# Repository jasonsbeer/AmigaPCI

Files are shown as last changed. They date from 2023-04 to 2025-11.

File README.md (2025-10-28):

<h1 align="center"></h1>

The AmigaPCI is an OCS/ECS Amiga computer in the ATX form factor. It provides a flexible CPU Local Bus port, five AUTOCONFIG PCI slots for expansion purposes such as video and sound, an on-board dual port ATA controller, and offers performance improvements over legacy Amiga designs.

## Features  
<list>
  <li>CPU Local Bus Card supports multiple CPU and fast RAM options</li>
  <li>Five AUTOCONFIG PCI 5V/Univeral slots</li>
  <li>PCI DMA allowing access to all Amiga and PCI address spaces</li>  
  <li>HID mouse and keyboard inputs</li>
  <li>Dual port IDE interface supporting up to 4 total devices</li>
  <li>Agnus 8372A or 8375 selectable by jumper</li>
  <li>Amiga Video Slot</li>
  <li>Floppy disk interface supports Amiga and PC drives in DD mode</li>
</list></br>

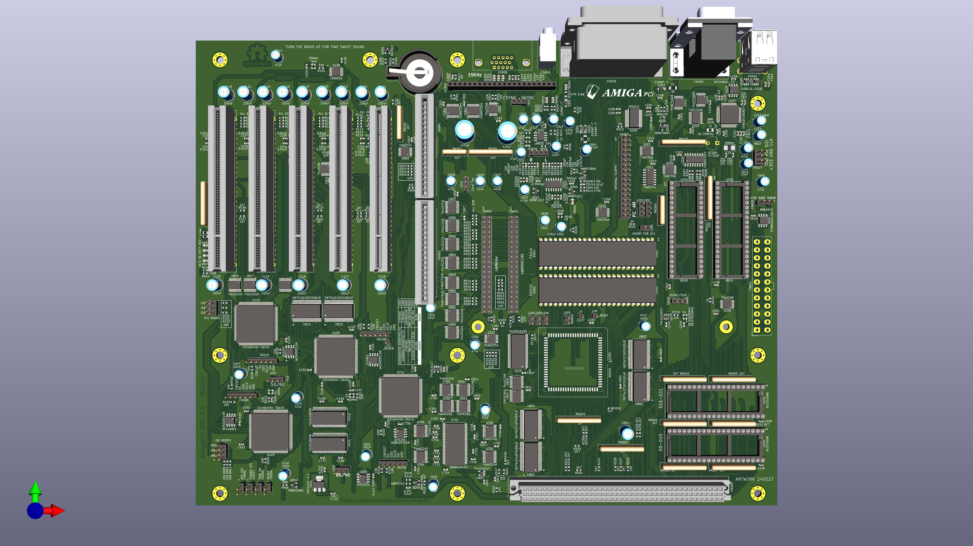
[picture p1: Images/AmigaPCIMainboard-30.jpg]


## Project Status  
**THIS IS A WORK IN PROGRESS AND IS SUBJECT TO CHANGE WITHOUT NOTICE.**

This is an active project and is currently in the prototype stage. Specifications are subject to change. Because this project is in the prototype stage, it is not recommended for general use at this time. There will be errors that adversely affect performance and the logic equations are not complete. If you choose to build this before final release, you accept all cost and risk associated with the decision.

I am not seeking hardware enhancement requests at this time, but feel free to post these in the issues section. Discussions can be found at Discord: https://discord.gg/NU7SPYfNFj.

## About the AmigaPCI Project

This is a hobby project. To me, the Amiga has a personality that PCs of any era cannot hope to replicate. I got my first Amiga, an A500, in 1992. In 1995, despite Commodore having gone out of business, I upgraded to a used A2000 with a GVP 030/SCSI card and flicker fixer. Even at this time we had a few Amiga shops hanging on. Around 1998 I relented and built a PC. The writing was on the wall for the Amiga and it was time to move on. The Amigas went into the closet, rarely to see the light. Sadly, like so many, I ended up selling my original machines only for my interest to rekindle years later. The purpose of my Amiga projects are to learn and hopefully share something of value with fellow Amigans by providing options for machines using modern components, whenever possible. This gave rise to the [A2000 EATX](https://github.com/jasonsbeer/Amiga-2000-EATX), the [N2630](https://github.com/jasonsbeer/Amiga-N2630), and now, the AmigaPCI.

# Building the AmigaPCI

[Ordering PCBs](pcb_order.md)  
[Assembly Notes](assembly.md)
[Hardware Information](hardware_info.md)  
[Programming the FPGAs](program_fpga.md)  

# Overview

## PCI Local Bus  
The PCI bus is based on the [PCI Local Bus Revision 2.3 specifications](/DataSheets/PCI/pci_23.pdf). The PCI Bridge implements a bidirectional asynchronous FIFO to facilitate data movements between the buses. Each slot is compatable with Universal and 5V PCI devices. All efforts are made to align implemented PCI features completely with the PCI Local Bus Revision 2.3. There are no undocumented PCI commands. Each slot is capable of supporting AUTOCONFIG for Amiga specific devices. Software configuration (Prometheus mode) is also available for non-Amiga specific hardware. The AmigaPCI supports true DMA, with each PCI device having total access to all PCI and Amiga address spaces.

## CPU Local Bus
The AmigaPCI main board has no CPU or fast ram. Instead, the CPU Local Bus port supports CPUs and AUTOCONFIG devices. The CPU Local Bus port is a DIN 41612 connector with 120 pins in 3 rows by 40 columns. The CPU local bus is discussed further in the [AmigaPCI Technical Reference Manual](/AmigaPCI_Technical_Manual.md). This approach allows fast RAM and other AUTOCONFIG devices be optimized for the clock speed and capabilities of the CPU device implemented.

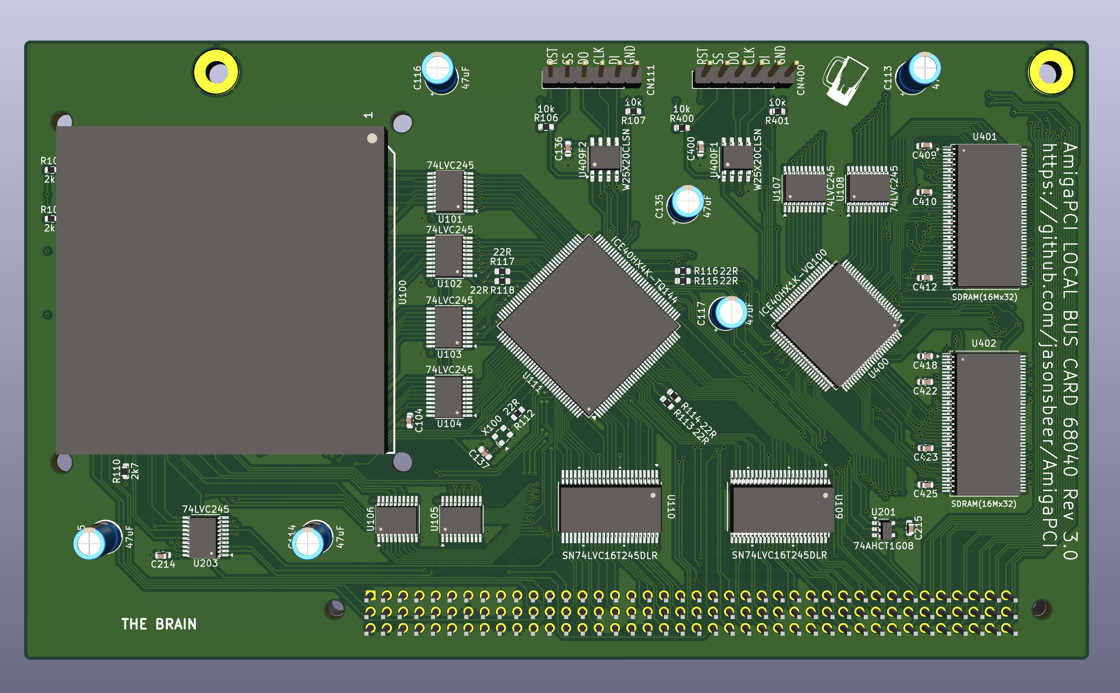
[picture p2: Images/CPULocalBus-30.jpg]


## Amiga Custom Chips  
The AmigaPCI must be populated with the Amiga OCS/ECS custom chips. The Amiga chipset is required to enable critical functions of the Amiga computer. See [Assembly Notes](assembly.md) for more information.

## Kickstart ROM  
Kickstart ROM version 3.2 or greater for the Amiga 1200 should be burned to 27C4096 EPROMs (DIP-40 footprint) for use by the AmigaPCI. Original Commodore Amiga Kickstart ROMs are not supported. 

## STM32F205 Microcontroller
The STM32F205 microcontroller supplies several functions to the AmigaPCI.

### HID
The AmigaPCI support human interface devices (HID) via the two USB ports. The mouse HID signals are shared with the JOY1 port (see Mouse and Joystick) via buffers. When there is active input from the HID mouse, the buffers are switched to only allow input from the HID port. When the HID mouse is not in active use, the buffers switch to allow input from JOY1. With this method, input from only one device is allowed at any time, with the mouse HID having priority.

### I2C
An internal I2C header is present on the AmigaPCI board as well as at the Local Bus Card.

### Real Time Clock
The STM32F205 emulates the capabilities of the xxxx real time clock chip. The clock is timed by an external 32.xxxkhz crystal and can be fine tuned by a variable capacitot.

### Voltage Monitors
All voltages can be monitored by reading registers from the real time clock address space.

### Internal temperature
The internal fan header RPM is controlled by a PWM signal.

## Audio  
The audio output is generated by Paula and run through the filter circuit as in the Amiga 4000. The audio output is supplied from a line level 3.5mm stereo jack. A CD audio header is included to support the input of analog line-level audio from optical drives or other devices. It is a 4-pin 2.54 pitch connector in the RGGL footprint, with pin 1 = R. This may be installed as a standard 4-pin male header or TE Connectivity part 5-103639-3, which is the MPC-2 locking header that has become ubiquitous.

## Video  
The 15KHz standard Amiga video is output via an HD15 connector. This allows easy connection to converter boxes or any monitors that support the 15KHz standard. This connector only includes the signals needed for video output. Other signals present on the orignal Amiga video port are not included.

## Mouse and Joystick
There are two legacy DB9 joystick port headers on the board. JOY1 is shared with the HID mouse input. In order to prevent signal contention with the HID mouse, the inputs from JOY1 are disconnected when the HID mouse is actively used. This prevents undesired behavior and allows only one device at a time to input signals, with the HID device having priority. See [HID](#hid). The input of JOY2 is not shared with other ports. 

## Serial  
The serial port is a male DB25 connector, which is stacked with the parallel female DB25 connector. The serial port is completely compatable with Amiga peripherals designed for the Amiga 500, 600, 1200, 2000, 3000, and 4000.

## Parallel  
The parallel port is a female DB25 connector, which is stacked with the serial male DB25 connector. The parallel port is completely compatable with legacy Amiga devices.

## Floppy Disk Drive  
The floppy disk interface is the primary way Amiga based computers store and retrieve external data. The AmigaPCI includes a header that supports two internal double density floppy disk drives.

In addition to supporting original Amiga floppy disk drives, the AmigaPCI supports PC floppy disk drives with double density floppies. An adaptation of Ian Steadman's [PC floppy interface](https://github.com/istedman/Floppy_adaptor) is implemented. The floppy drive hardware type (Amiga or PC) is set by jumper.

>[!NOTE]
>You must use either Amiga disk drives or PC disk drives. Do not mix the two types.  

## ATA  
The AmigaPCI includes a dual-port host terminated ATA device interface using [lide.device](https://github.com/LIV2/lide.device).

## Video Slot  
The AmigaPCI includes the Amiga OCS/ECS video bus. This allows for the use of OCS/ECS compatable video devices with the AmigaPCI.

# References

[AmigaPCI PCI Hardware Developer Reference](/AmigaPCI_PCI_Dev_Guide.md)  
[AmigaPCI Hardware Reference](/AmigaPCI_Technical_Manual.md)  
[PCI Local Bus Revision 2.3 specifications](/DataSheets/PCI/pci_23.pdf)  

# Revision History 
**Rev 6.0**  Current engineering prototype. 

# Acknowledgements  
Chris Hooper for his work on the STM32F205 microcontroller code.  
Frédéric Requin for helping me better understand the ATA protocol.  
Ian Steadman for his [Amiga PC floppy interface](https://github.com/istedman/Floppy_adaptor) design.

# License
Floppy interface modifications from Ian Steadman (noted in schematic) released under the GNU GENERAL PUBLIC LICENSE, Version 3.

<p xmlns:cc="http://creativecommons.org/ns#" xmlns:dct="http://purl.org/dc/terms/"><a property="dct:title" rel="cc:attributionURL" href="https://github.com/jasonsbeer/AmigaPCI">AmigaPCI</a> by <a rel="cc:attributionURL dct:creator" property="cc:attributionName" href="https://github.com/jasonsbeer">Jason Neus</a> is licensed under <a href="https://creativecommons.org/licenses/by-nc/4.0/?ref=chooser-v1" target="_blank" rel="license noopener noreferrer" style="display:inline-block;">Creative Commons Attribution-NonCommercial 4.0 International</a></p>

**Last Update: 28-OCT-2025**

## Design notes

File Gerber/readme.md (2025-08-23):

The gerbers are in the appropriate folder. Pick and place files and JLCPCB BOMs with parts numbers are also found in each folder. File names containing "SMT" are surface mount components only. File names containing "ALL PARTS" include SMT and through hole parts. Not all parts are necessarily populated in the BOM, as dictated by availability and (crazy) price at the time the files were created. Previous revision hardware can be found in the Archive folder.

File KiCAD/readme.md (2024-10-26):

KiCAD files. Current revisions are in this folder. Development (future) revisions are in the DEV folder. Deprecated versions are found in the Archive folder.

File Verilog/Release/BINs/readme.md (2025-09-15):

You will find the current FPGA BIN files here. These will always be the most recent revision.

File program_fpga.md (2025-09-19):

# Programming the FPGA Flash Memory
There are four Lattice iCE40 FPGAs on the AmigaPCI board. Each FPGA has an associated flash memory module to store the FPGA configuration, which is loaded by the FPGA at startup. Each flash memory module has a programming header. The header is identified similarly to the associated FPGA. For example, CN712 programs the flash module for U712. CN409 for U409, etc.

## Programming with a FT232H USB to SPI Board
We will discuss programming the flash memory modules using iceprog with cheap FTDI FT232H interface boards. Such an example is the [Adafruit FT232H](https://www.adafruit.com/product/2264). Similar boards can be obtained from other manufacturers. The following steps describe how to program the flash modules. Do not leave the AmigaPCI powered on for longer than necessary during the programming process.

It is recommended to program the FPGA's in specific order. Program any FPGAs on the local bus card first. If you have the AmigaPCI local bus card ("THE BRAIN") program these in this order: U400, U111. Then, on the AmigaPCI, program these in this order: U409, U712, U110, U109.

1. Install [icestorm](https://github.com/YosysHQ/icestorm).  

   Debian:
   ```
   sudo apt install fpga-icestorm
   ```
   Fedora:
   ```
   sudo dnf install icestorm
   ```

2. If it is on, turn off the AmigaPCI.
3. Connect the FT232H board to the desired FPGA programming port.
   
   AmigaPCI|Adafruit FT232H|C232HM MPSSE
   -|-|-
   GND|GND|Black/GND
   SDI|D1/MOSI|Yellow/DO
   SCLK|D0/SCK/SCL|Orange/SK
   SDO|D2/MISO|Green/DI
   SS|D4|Gray/GPIOL0
   CRST|D7|Blue/GPIOL3

3. Turn the AmigaPCI on.  
4. Execute iceprog with the correct BIN file.  

   ```
   iceprog U712.bin
   ```
5. Repeat steps 2 through 5 for each FPGA. Power cycle the AmigaPCI once complete.

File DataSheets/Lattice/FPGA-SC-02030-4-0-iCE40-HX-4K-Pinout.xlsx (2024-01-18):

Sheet: Pinout
iCE40 Pinout HX4K
Pin Function | Pin Type | Bank | (BG121) 121-Ball caBGA Ball Number | (CB132) 132-Ball csBGA Ball Number | (TQ144) 144-Pin TQFP Pin Number
IOL_2A | DPIO | 3 | B1 | B1 | 1
IOL_2B | DPIO | 3 | B2 | C1 | 2
IOL_3A | DPIO | 3 | - | - | 3
IOL_3B | DPIO | 3 | - | - | 4
GND | GND | GND | - | A9 | 5
VCCIO_3 | VCCIO | VCCIO | - | E3 | 6
IOL_4A | DPIO | 3 | C4 | C3 | 7
IOL_4B | DPIO | 3 | C3 | D3 | 8
IOL_5A | DPIO | 3 | C2 | D1 | 9
IOL_5B | DPIO | 3 | C1 | E1 | 10
IOL_8A | DPIO | 3 | E1 | D4 | 11
IOL_8B | DPIO | 3 | D1 | E4 | 12
IOL_9A | DPIO | 3 | D2 | F4 | -
IOL_9B | DPIO | 3 | D3 | F3 | -
GND | GND | GND | - | F1 | 13
GND | GND | GND | - | F7 | 14
IOL_10A | DPIO | 3 | E2 | H4 | 15
IOL_10B | DPIO | 3 | E3 | G4 | 16
IOL_12A | DPIO | 3 | F1 | J3 | 17
IOL_12B | DPIO | 3 | F2 | J1 | 18
IOL_13A | DPIO | 3 | F4 | G3 | 19
IOL_13B_GBIN7 | GBIN | 3 | F3 | G1 | 20
IOL_14A_GBIN6 | GBIN | 3 | G1 | H1 | 21
IOL_14B | DPIO | 3 | G2 | H3 | 22
IOL_17A | DPIO | 3 | G3 | - | 23
IOL_17B | DPIO | 3 | H3 | - | 24
IOL_18A | DPIO | 3 | H1 | K3 | 25
IOL_18B | DPIO | 3 | H2 | K4 | 26
VCC | VCC | VCC | - | F8 | 27
IOL_23A | DPIO | 3 | J1 | L1 | 28
IOL_23B | DPIO | 3 | K1 | M1 | 29
VCCIO_3 | VCCIO | VCCIO | E4 | J6 | 30
IOL_24A | DPIO | 3 | - | - | 31
IOL_24B | DPIO | 3 | - | - | 32
IOL_25A | DPIO | 3 | K2 | N1 | 33
IOL_25B | DPIO | 3 | J2 | P1 | 34
IOB_56 | PIO | 2 | L1 | P2 | 37
IOB_57 | PIO | 2 | J3 | - | 38
IOB_59 | PIO | 2 | - | P3 | -
IOB_61 | PIO | 2 | L2 | - | 39
VCC | VCC | VCC | D8 | G6 | 40
IOB_63 | PIO | 2 | K3 | M4 | 41
IOB_64 | PIO | 2 | J4 | M3 | 42
IOB_71 | PIO | 2 | L3 | L5 | 43
IOB_72 | PIO | 2 | L4 | L4 | 44
IOB_73 | PIO | 2 | K4 | P4 | 45
IOB_74 | PIO | 2 | - | P5 | -
IOB_77 | PIO | 2 | - | M6 | -
IOB_78 | PIO | 2 | J5 | L6 | -
VCCIO_2 | VCCIO | VCCIO | H6 | J9 | 46
IOB_79 | PIO | 2 | K5 | M7 | 47
IOB_80 | PIO | 2 | - | - | 48
IOB_81_GBIN5 | GBIN | 2 | L5 | P7 | 49
IOB_82_GBIN4 | GBIN | 2 | K6 | P8 | 52
GNDPLL0 | GNDPLL | GNDPLL | L6 | L7 | 53
VCCPLL0 | VCCPLL | VCCPLL | J6 | M8 | 54
IOB_87 | PIO | 2 | H7 | L8 | -
IOB_89 | PIO | 2 | K7 | P9 | -
IOB_91 | PIO | 2 | J8 | M9 | 55
IOB_94 | PIO | 2 | L7 | - | 56
VCCIO_2 | VCCIO | VCCIO | - | M5 | 57
GND | GND | GND | E5 | G7 | 59
IOB_95 | PIO | 2 | - | - | 60
IOB_96 | PIO | 2 | - | - | 61
IOB_102 | PIO | 2 | - | - | 62
IOB_103_CBSEL0 | PIO | 2 | L8 | L9 | 63
IOB_104_CBSEL1 | PIO | 2 | H9 | P10 | 64
CDONE | CONFIG | 2 | K8 | M10 | 65
CRESET_B | CONFIG | 2 | L9 | L10 | 66
IOB_105_SDO | SPI | SPI | K9 | M11 | 67
IOB_106_SDI | SPI | SPI | J9 | P11 | 68
GND | GND | GND | E6 | G8 | 69
IOB_107_SCK | SPI | SPI | L10 | P12 | 70
IOB_108_SS | SPI | SPI | K10 | P13 | 71
VCC_SPI | SPI | SPI | L11 | L11 | 72
IOR_109 | PIO | 1 | - | M12 | 73
IOR_110 | PIO | 1 | - | P14 | 74
IOR_111 | PIO | 1 | - | L12 | 75
IOR_112 | PIO | 1 | - | N14 | 76
NC | NC | NC | - | M14 | 77
IOR_114 | PIO | 1 | J11 | L14 | 78
IOR_115 | PIO | 1 | K11 | K12 | 79
IOR_116 | PIO | 1 | H10 | K11 | 80
IOR_117 | PIO | 1 | J10 | K14 | 81
IOR_118 | PIO | 1 | G8 | J12 | 82
IOR_119 | PIO | 1 | H11 | J11 | 83
IOR_120 | PIO | 1 | G10 | H12 | 84
IOR_128 | PIO | 1 | G9 | H11 | 85
IOR_129 | PIO | 1 | G11 | G12 | -
GND | GND | GND | E7 | G9 | 86
IOR_136 | PIO | 1 | F10 | G11 | 87
IOR_137 | PIO | 1 | F9 | F12 | 88
VCCIO_1 | VCCIO | VCCIO | - | F9 | 89
IOR_138 | PIO | 1 | - | - | 90
IOR_139 | PIO | 1 | - | - | 91
VCC | VCC | VCC | D4 | H9 | 92
IOR_140_GBIN3 | GBIN | 1 | F11 | F14 | 93
IOR_141_GBIN2 | GBIN | 1 | E10 | G14 | 94
IOR_144 | PIO | 1 | E9 | F11 | 95
IOR_146 | PIO | 1 | E8 | E11 | 96
IOR_147 | PIO | 1 | D9 | E12 | 97
IOR_148 | PIO | 1 | E11 | E14 | 98
IOR_152 | PIO | 1 | D11 | D14 | 99
IOR_154 | PIO | 1 | D10 | C14 | -
VCCIO_1 | VCCIO | VCCIO | F8 | H14 | 100
IOR_160 | PIO | 1 | C11 | D12 | 101
IOR_161 | PIO | 1 | B11 | B14 | 102
GND | GND | GND | F5 | H6 | 103
IOR_164 | PIO | 1 | - | - | 104
IOR_165 | PIO | 1 | - | - | 105
IOR_166 | PIO | 1 | - | - | 106
IOR_167 | PIO | 1 | - | - | 107
VPP_2V5 | VPP | VPP | C10 | A14 | 108
VPP_FAST | VPP | VPP | B10 | A13 | 109
IOT_168 | PIO | 0 | A11 | - | 110
VCC | VCC | VCC | H4 | J4 | 111
IOT_169 | PIO | 0 | - | - | 112
IOT_170 | PIO | 0 | A10 | A12 | 113
IOT_171 | PIO | 0 | - | - | 114
IOT_172 | PIO | 0 | C9 | C12 | 115
IOT_173 | PIO | 0 | - | - | 116
IOT_174 | PIO | 0 | B9 | C11 | 117
IOT_177 | PIO | 0 | B8 | D10 | 118
IOT_178 | PIO | 0 | A9 | D11 | 119
IOT_179 | PIO | 0 | C8 | A11 | 120
IOT_181 | PIO | 0 | D7 | A10 | 121
IOT_186 | PIO | 0 | - | C10 | -
IOT_188 | PIO | 0 | - | D9 | -
IOT_190 | PIO | 0 | A8 | C9 | 122
VCCIO_0 | VCCIO | VCCIO | D6 | A8 | 123
IOT_191 | PIO | 0 | C7 | - | 124
IOT_192 | PIO | 0 | A7 | - | 125
VCCPLL1 | VCCPLL | VCCPLL | C6 | C8 | 126
GNDPLL1 | GNDPLL | GNDPLL | C5 | D8 | 127
IOT_197_GBIN1 | GBIN | 0 | B7 | A7 | 128
IOT_198_GBIN0 | GBIN | 0 | B6 | A6 | 129
IOT_200 | PIO | 0 | - | C7 | -
IOT_202 | PIO | 0 | - | D7 | -
IOT_206 | PIO | 0 | A6 | C6 | 130
IOT_207 | PIO | 0 | A5 | D6 | -
IOT_208 | PIO | 0 | B5 | A5 | -
IOT_211 | PIO | 0 | A4 | D5 | -
VCCIO_0 | VCCIO | VCCIO | - | F6 | 131
GND | GND | GND | F6 | H7 | 132
IOT_212 | PIO | 0 | D5 | C5 | 134
IOT_213 | PIO | 0 | - | - | 135
IOT_214 | PIO | 0 | - | - | 136
IOT_215 | PIO | 0 | - | - | 137
IOT_216 | PIO | 0 | - | - | 138
IOT_217 | PIO | 0 | - | - | 139
GND | GND | GND | F7 | H8 | 140
IOT_219 | PIO | 0 | B4 | A4 | 141
IOT_220 | PIO | 0 | - | - | 142
IOT_221 | PIO | 0 | B3 | C4 | 143
IOT_222 | PIO | 0 | A2 | A3 | 144
IOT_223 | PIO | 0 | A3 | A2 | -
IOT_225 | PIO | 0 | A1 | A1 | -
VCC | VCC | VCC | H8 | J7 | -
NC | NC | NC |  | - | 35
NC | NC | NC |  | - | 36
NC | NC | NC |  | - | 50
NC | NC | NC |  | - | 51
NC | NC | NC |  | - | 58
NC | NC | NC |  | - | 133
GND | GND | GND | G5 | J14 | -
GND | GND | GND | G6 | J8 | -
GND | GND | GND | G7 | L3 | -
GND | GND | GND | H5 | P6 | -
VCCIO_3 | VCCIO | VCCIO | G4 | K1 | -
IOB_86 | PIO | 2 | J7 | - | -

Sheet: Revision History
Version | Date | Description
4.0 | 2021/10/29 | Added the missing pins (D6, H4, H5, and J7)
3.0 | 2017/05/5 | add "BG121" for "121-Ball caBGA"(new 9x9 mm package ucBGA121), Revision "iCE40HX08.pkt 1.1"
2.1 | 2013-06-13 | Included package ordering code.
2.0 | 2013-03-13 | Updated table format to include all packages
1.0 | 10/1/2012 | Changed name from "TQ144" to "144-pin TQFP" Production Release
0.92 | 2011-12-14 | Package drawing, removed option notes 6 and 7
0.91 | 2011-11-13 | 1K pins 40, 49, 50, 52, 133, 134 updated
0.9 | 2011-10-31 | Preliminary

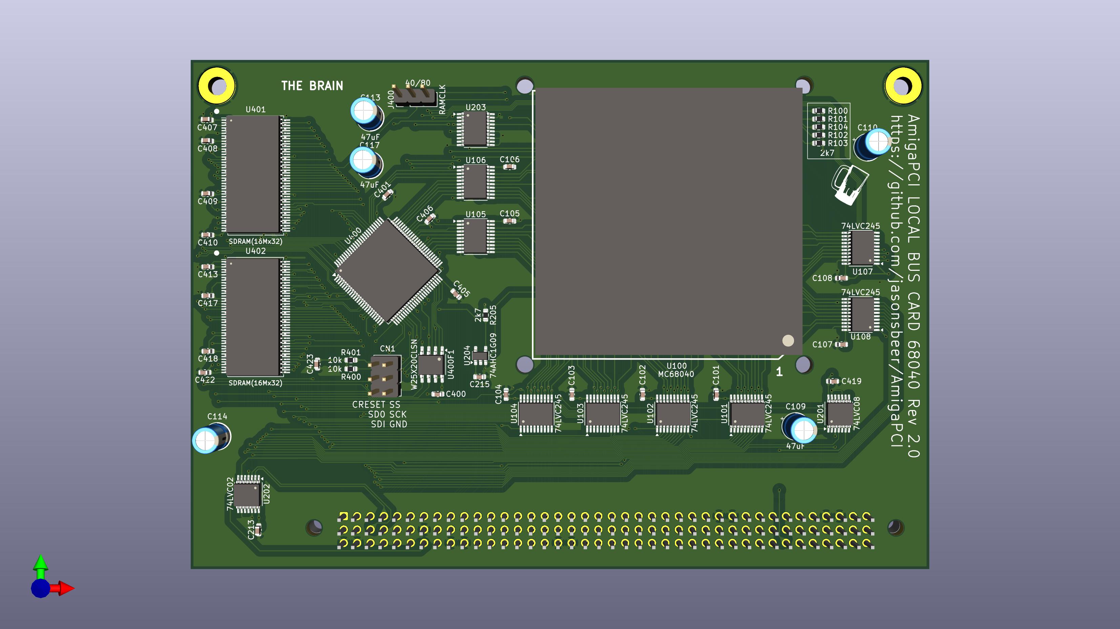
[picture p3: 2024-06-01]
Images/CPULocalBus-20.jpg

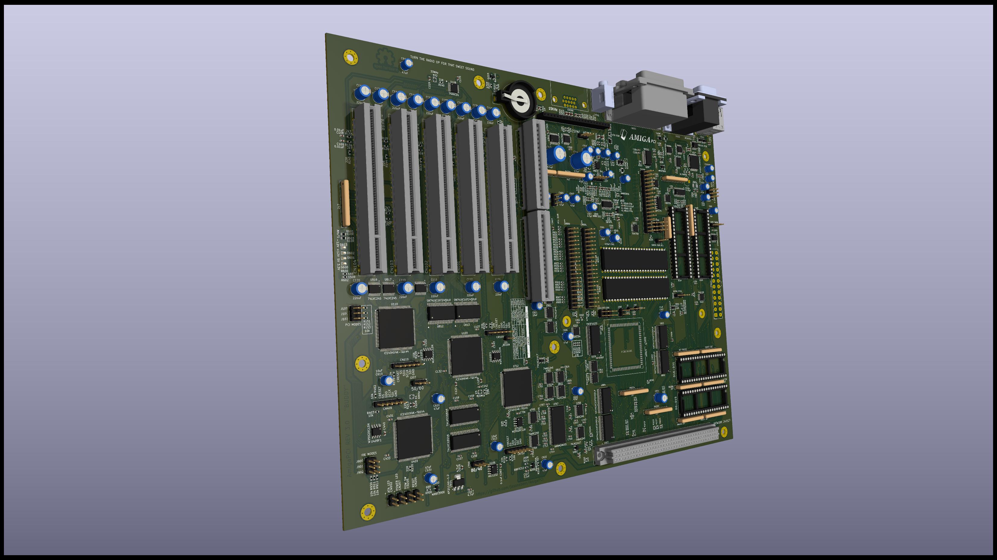
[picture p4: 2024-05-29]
Images/AmigaPCIMainboard-30a.jpg

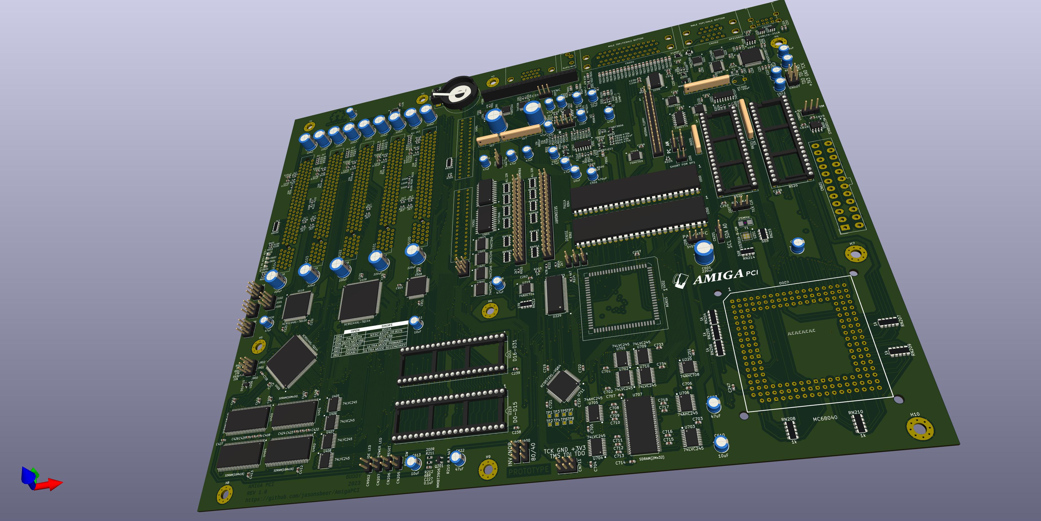
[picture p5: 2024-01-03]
Images/AmigaPCIMainboard.jpg

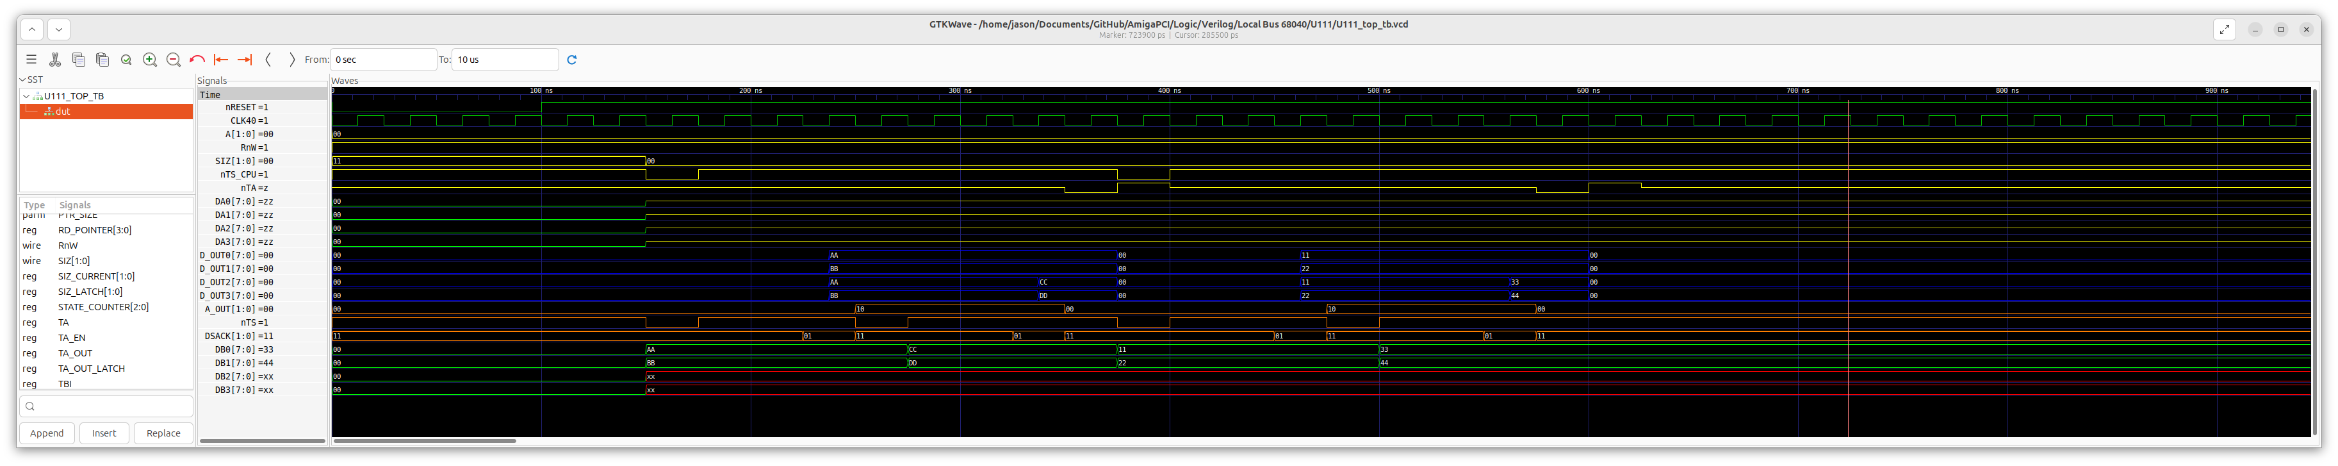
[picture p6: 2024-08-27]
DataSheets/TimingDiagrams/Bus Sizing/LONG WORD READ FROM WORD PORT.png

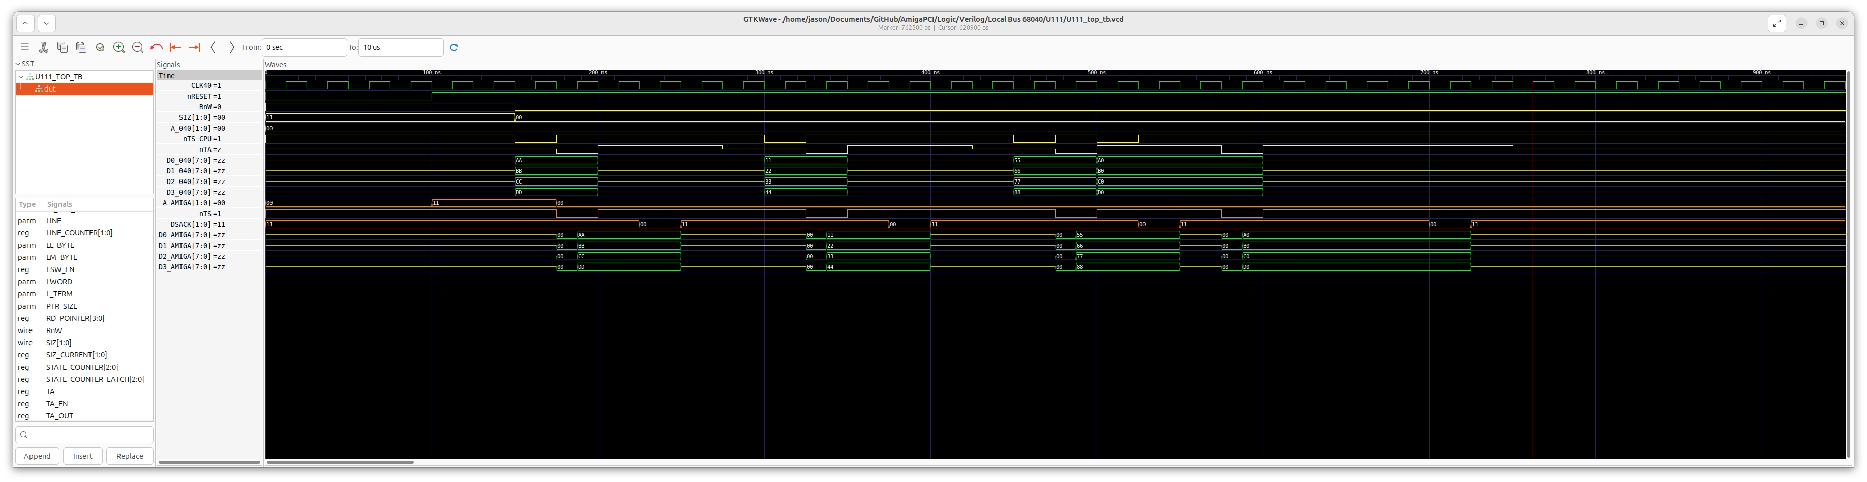
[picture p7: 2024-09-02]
DataSheets/TimingDiagrams/Bus Sizing/LONG WORD WRITE TO LONG WORD PORT.png

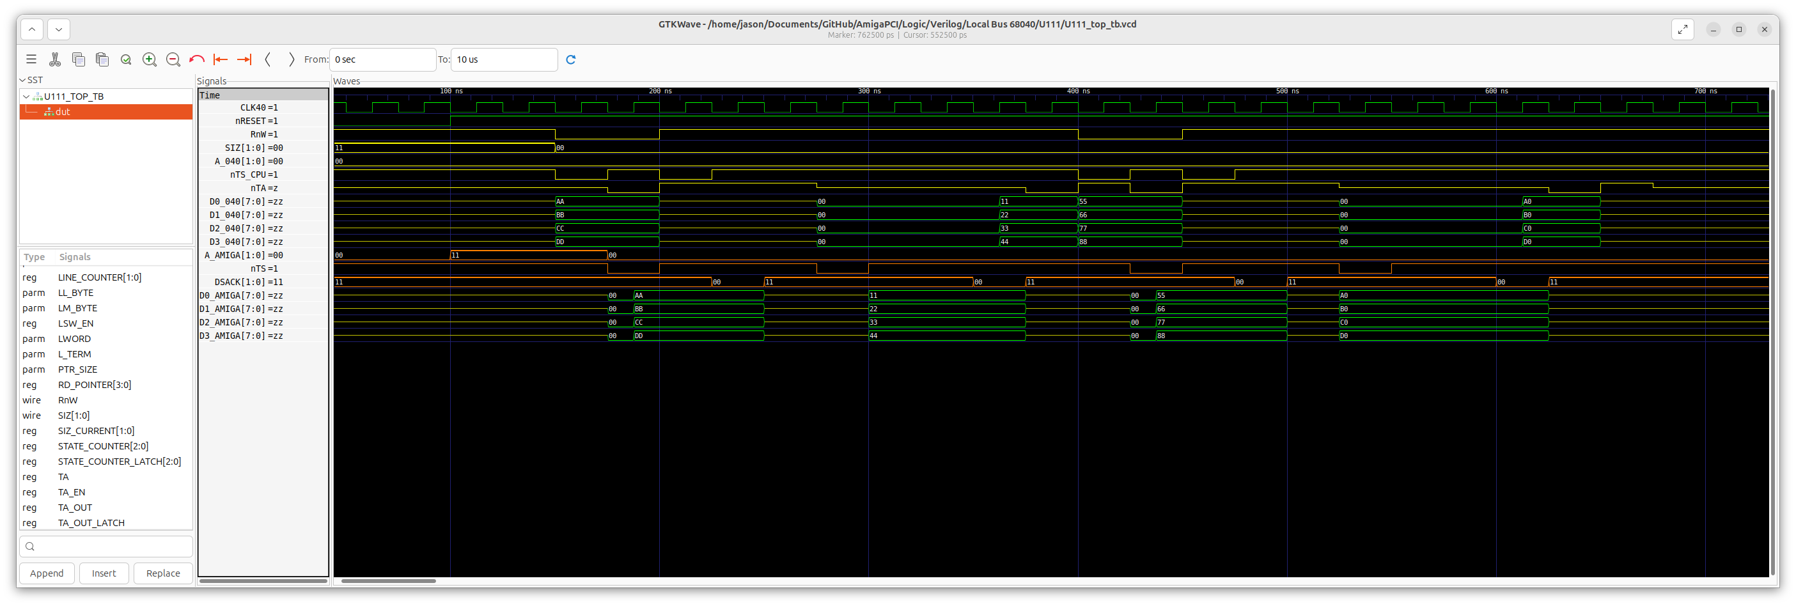
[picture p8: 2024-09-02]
DataSheets/TimingDiagrams/Bus Sizing/ALTERNATING RW LONG WORD TO LONG WORD PORT.png

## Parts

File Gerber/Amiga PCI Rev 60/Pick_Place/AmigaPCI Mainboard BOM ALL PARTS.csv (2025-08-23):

Value | Reference | Footprint | LCSC Part Number
7pF | C222 | 603 | C53775
13pF | C220,C221 | 603 | C34243
47pF | C307 | 603 | C1671
100pF | C301,C304,C312,C315,C316 | 603 | C14858
330pF | C518,C519 | 603 | C1664
1000pF | C234,C235,C236 | 603 | C1588
3900pF | C516,C517 | 603 | C170145
6800pF | C515,C524 | 603 | C1631
0.01uF | C100,C101,C102,C103,C104,C105,C106,C107,C108,C109,C210,C514 | 603 | C57112
0.047uF | C202,C203,C204,C205,C512,C513 | 603 | C1622
0.1uF | C123,C124,C125,C126,C127,C128,C129,C130,C131,C132,C135,C137,C139,C140,C141,C142,C143,C144,C145,C146,C147,C148,C150,C152,C153,C156,C157,C158,C159,C200,C201,C206,C207,C208,C209,C211,C213,C214,C215,C218,C219,C223,C224,C227,C228,C229,C230,C231,C232,C233,C238,C239,C241,C243,C246,C249,C250,C251,C252,C253,C256,C257,C258,C259,C261,C262,C263,C267,C302,C303,C305,C306,C420,C421,C429,C430,C431,C432,C433,C434,C435,C436,C438,C440,C500,C510,C511,C615,C616,C701,C702,C703,C704,C705,C706,C707,C708,C709,C710,C711,C712,C713,C714,C715,C716,C717,C718,C719,C720,C721,C722,C723,C724,C725,C726,C727,C728,C730,C736,C802,C803,C804,C805,C806,C807,C808,C809,C810,C811,C812,C813,C814,C815,C816,C817,C818,C819,C820,C821,C822,C823,C824,C825,C900,C901,C902,C904,C905,C906,C907,C908 | 603 | C14663
0.22uF | C300,C506,C508,C509 | 603 | C21120
1uF | C212 | 603 | C15849
4.7uF | C507 | Radial_D5.0mm_P2.00mm | C88759
4.7uF | C617,C618,C623,C626 | 603 | C19666
10uF | C136,C138,C149,C151,C437,C439,C729,C735 | 603 | C96446
10uF | C608,C611,C613,C619,C625 | Radial_D5.0mm_P2.00mm | C88726
22uF | C237,C240,C520,C521 | Radial_D5.0mm_P2.00mm | C88755
47uF | C522,C523,C600,C602,C603,C604,C605,C606,C607,C609,C610,C614,C620,C621,C622,C624 | Radial_D5.0mm_P2.00mm | C88724
68uF | C216,C217 | Radial_D5.0mm_P2.00mm | C439891
220uF | C110,C111,C112,C113,C114,C115,C116,C117,C118,C119,C120,C121,C133,C134,C601 | Radial_D6.3mm_P2.50mm | C141282
470uF | C313,C314,C501 | Radial_D10.0mm_P5.00mm | C59353
1R | R302,R500,R503,R504 | 603 | C22936
4A | F1,F2 | 1206 | C1972812
22R | R140,R141,R142,R143,R144,R145,R213,R215,R216,R217,R219,R220,R272,R273,R274,R275,R307,R907,R908,R909,R910,R913,R914,R915,R916,R917,R918,R919,R920,R921,R922,R923,R924,R925,R926,R927,R928,R929,R931,R932,R933,R934,R935,R936 | 603 | C23345
47R | R222,R226,R230,R231,R232,R233,R237,R301,R304,R313,R314,R315,R316,R317,R318,R319,R320,R321,R322,R323,R324 | 603 | C23182
68R | R204,R205,R206,R207,R211,R218,R251,R252 | 603 | C25254
100R | R156,R157,R160,R161,R400,R401,R700,R701 | 603 | C22775
200R | R212,R247 | 603 | C8218
470R | R201 | 603 | C23179
750R | R505,R507 | 603 | C23241
1k | R214,R224,R225,R227,R248,R249,R254,R255,R256,R257,R258,R259,R262,R263,R264,R268,R303,R309,R311,R312,R501,R502,R522,R523,R524,R526,R900 | 603 | C21190
1k | RN305 | SIP6 | C1357978
2k | R602,R906 | 603 | C22975
8362 | U300 | DIP-48 | C5510465
8364 | U500 | DIP-48 | C5510465
DIP-40 Socket | U203,U204,U210,U211 | DIP-40 | C2332
10k | R154,R155,R158,R159,R200,R202,R203,R208,R209,R223,R228,R229,R241,R265,R266,R279,R300,R305,R308,R402,R403,R509,R510,R511,R513,R515,R516,R517,R525,R702,R703,R901,R902,R903,R904,R911,R912 | 603 | C25804
10k | RN211 | SIP9 | C8692
32.768KHz | Y4 | 2Pin_3.2x1.5mm | C20340322
470k | R508,R514 | 603 | C23178
6MHz | X1 | 4Pin_2.5x2.0mm | C2451074
8MHz | Y1 | 2Pin_5.0x3.2mm | C5564812
28.63636MHz | X3 | 4Pin_2.5x2.0mm | C1670933
33MHz | X2 | 4Pin_2.5x2.0mm | C17506154
1x03 Pin Header | J201,J202,J303,J209,J208,J207,J206,CN209 | 1x03_P2.54mm_Vertical | C49257
1k2 | R506 | 603 | C22765
1N4148 | D200,D204 | SOD-323 | C118873
2k2 | R267,R280,R281,R600 | 603 | C4190
2k4 | R518,R519 | 603 | C22940
2k7 | R101,R102,R103,R104,R105,R106,R107,R108,R109,R110,R111,R112,R113,R114,R115,R116,R117,R118,R119,R120,R121,R122,R123,R124,R125,R126,R127,R128,R129,R130,R131,R132,R133,R134,R135,R136,R137,R138,R139,R146,R147,R148,R149,R150,R162,R221,R234,R235,R236,R238,R239,R240,R242,R243,R244,R245,R246,R269,R270,R271,R276,R277,R278,R512 | 603 | C13167
2k7 | RN100,RN200,RN201,RN202,RN203,RN204,RN205,RN206,RN207 | SIP9 | C5902812
2k7 | RN101 | SIP7 | C51837
47R 0.5W | R310 | 805 | C560533
4k7 | R210,R520,R521 | 603 | C23162
4k7 | RN208,RN213,RN302 | SIP5 | C11392
4k7 | RN301 | SIP9 | C9112
5-20pF | VC200 | 6mm Lead Spacing | C3273401
5k1 | R260,R261 | 603 | C23186
5k1 | R601,R603 | 805 | C27834
74AHC04 | U108,U219 | TSSOP-14 | C415550
74AHC1G09 | U232 | SOT23-5 | C840099
74AHCT157 | U224 | SOIC-16 | C5969
74AHCT244 | U301,U302 | TSSOP-20 | C135583
74AHCT245 | U201 | TSSOP-20 | C173388
74CBT16233 | U229 | SSOP-56 | C2674759
74HCT00 | U213 | TSSOP-14 | C8206
74HCT03 | U215 | TSSOP-14 | C546492
74HCT08 | U209,U305 | TSSOP-14 | C131488
74HCT74 | U212,U303 | TSSOP-14 | C141335
74HCT4066 | U221,U222 | TSSOP-14 | C26433
74LVC08 | U220,U231,U815 | TSSOP-14 | C6053
74LVC245 | U701,U702,U703,U704,U705,U706,U806,U807,U808,U809,U812,U813,U814,U816,U817,U818,U819,U900,U901,U902,U903,U904,U905 | TSSOP-20 | C7848
74LVC373 | U906,U907 | TSSOP-20 | C485083
74LVC16646 | U111,U112,U810 | SSOP-56 | C2869631
74LVC2G34 | U200 | SOT -363 | C14461
_KBRST | CN210 | PinHeader_1x01_P2.54mm_Vertical | C81276
2X03 Pin Header | AGNUS1,JIDE1,JPCI1 | 2x03_P2.54mm_Vertical | C124384
Agnus_MULTI | U202 | PLCC-84 | C5445002
AO3400A | Q202 | SOT-23 | C347475
AP2114H-1.2 | U601 | SOT-223 | C94854
AP2114H-3.3 | U600 | SOT-223 | C150716
AP2156SG-13 | U228 | SOIC-8 | C88233
ATX-24 | CN601 | 2x12_P4.20mm_Vertical | C114088
AudioJack | CN501 | SJ1-3533NG_Horizontal | C4992459
AZ75232G | U205,U207 | TSSOP-20 | C444988
Battery_Cell | BT2 | Keystone_103_1x20mm | C238065
BZT52C5V1 | D205 | SOD-123 | C2117
Case Fan | CN205 | 1x04_P2.54mm_Vertical | C240840
CASE HDR | JCASE1 | 2x04_P2.54mm_Vertical | C7430400
DB15_Female_HighDensity | CN300 |  | C379814
DB25_Stack_FemaleAndMale | CN203 | DSUB-25_Stack_Female_Bottom_Male_Top | C17554757
DSP/DVD (RGGL) | CN500 | 1x04_P2.54mm_Vertical | C306099
ESDS452 | D206,D207,D208,D209,D210,D211,D212 | SOT-23 | C37574382
I2C | CN206 | 1x04_P2.54mm_Vertical | C124378
ICE40HX4K-TQ144 | U109,U110,U409,U712 | LQFP-144 | C1521989
INTERNAL FLOPPY | CN204 | PinHeader_2x17_P2.54mm | C2685134
LED | D203,D600,D601,D602,D603 | 603 | C2286
LF347 | U501 | SOIC-14 | C7917
LM833 | U502 | SOIC-8 | C127074
LM79L05 | U602 | SOIC-8 | C7555
MIC1232 | U206 | SOIC-8 | C627729
MMBFJ211 | Q500,Q501 | SOT-23 | C3290016
MMBT3904 | Q200 | SOT-23 | C84104
MMBT3906 | Q201,Q502,Q900 | SOT-23 | C75549
PCI32-5V | CN100,CN101,CN102,CN103,CN104 | 1.27mm Direct Insert 120P | C4900616
ATA HEADER | CN900,CN901 | PinHeader_2x20_P2.54mm_Vertical | C429965
1x02 Pin Header | J200,J203,J210,TP_109 | 1x02_P2.54mm_Vertical | C124375
ROM WAIT | J212 | 2x02_P2.54mm_Vertical | C66690
S1MWF-7 | D201,D202,D301,D400 | SOD-123 | C460736
SDRAM(8Mx32) | U707 | TSOP-II-86 | C1351836
SN74LVC16T245DLR | U802,U803,U804,U805 | BSSOP-48 | C2682002
SST39VF1601C | U223 | TSOP-I-48 | C184156
STM32F205RETx | U227 | LQFP-64 | C66278
Programming Header | CN227,CN109,CN110,CN409,CN712 | 1x06_P2.54mm_Vertical | C37208
USB_A_Stacked | CN201 | USB-A | C5366339
USBLC6-2SC6 | U225,U226 | SOT-23 | C7519
Video-Slot | CN301,CN302 | 2x18_P2.54mm_Horizontal | C5173302
VIDIOT | HY300 | PinSocket_1x22_P2.54mm_Vertical | C6358405
W25X20CLSN | U109F1,U110F1,U409F1,U712F1 | SOIC-8 | C34591

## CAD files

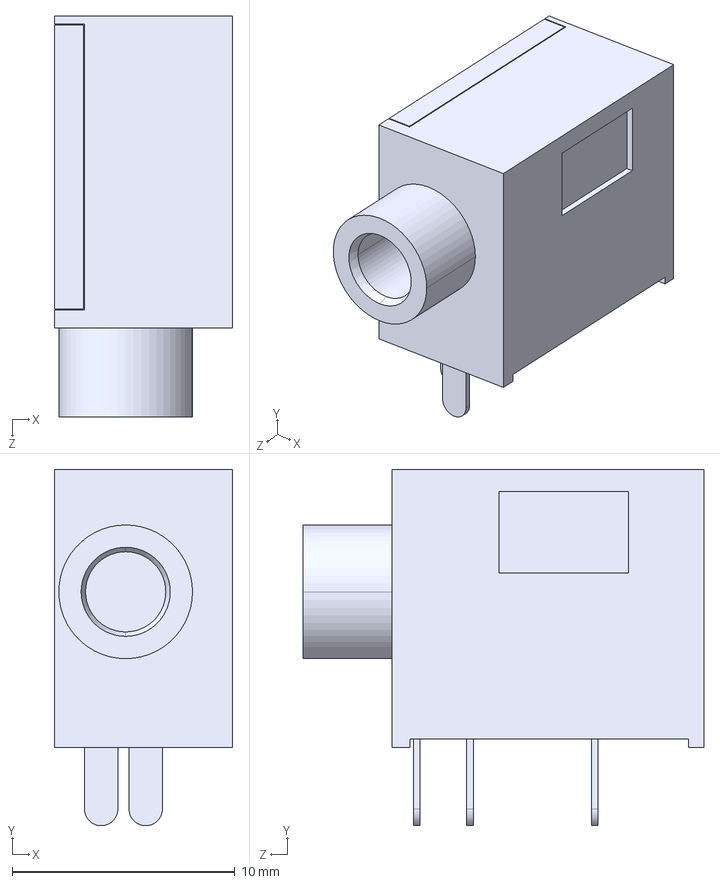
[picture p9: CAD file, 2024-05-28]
KiCAD/AmigaPCI Mainboard-KiCAD REV 60/AmigaPCI-Footprints/CUI_DEVICES_SJ1-3533N.step
8.00 x 16.0 x 18.0 mm

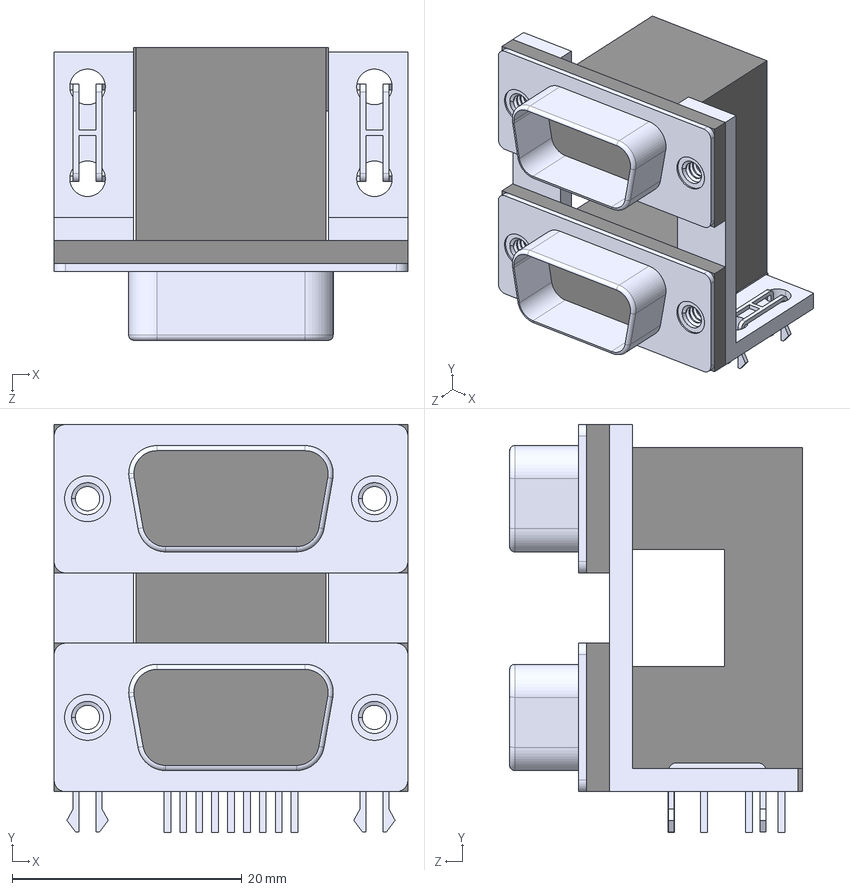
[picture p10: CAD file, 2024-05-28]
KiCAD/AmigaPCI Mainboard-KiCAD REV 60/AmigaPCI-Footprints/L17H2110130.step
30.8 x 35.5 x 25.5 mm

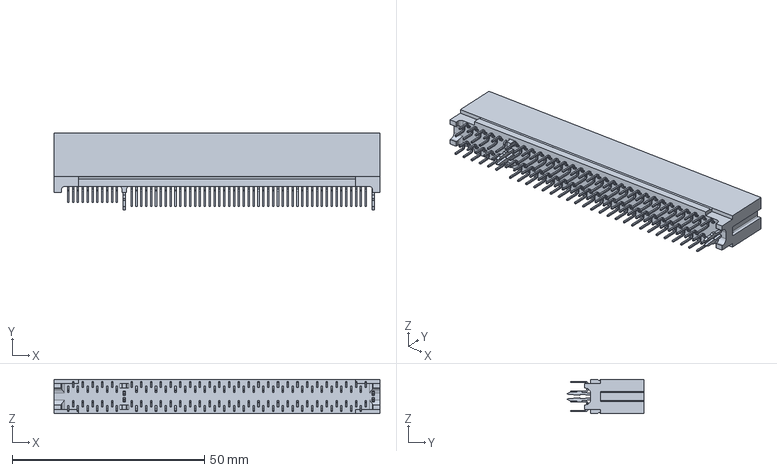
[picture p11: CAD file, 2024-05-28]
KiCAD/AmigaPCI Mainboard-KiCAD REV 60/AmigaPCI-Footprints/1-5145167-2.STEP
84.8 x 20.1 x 8.89 mm

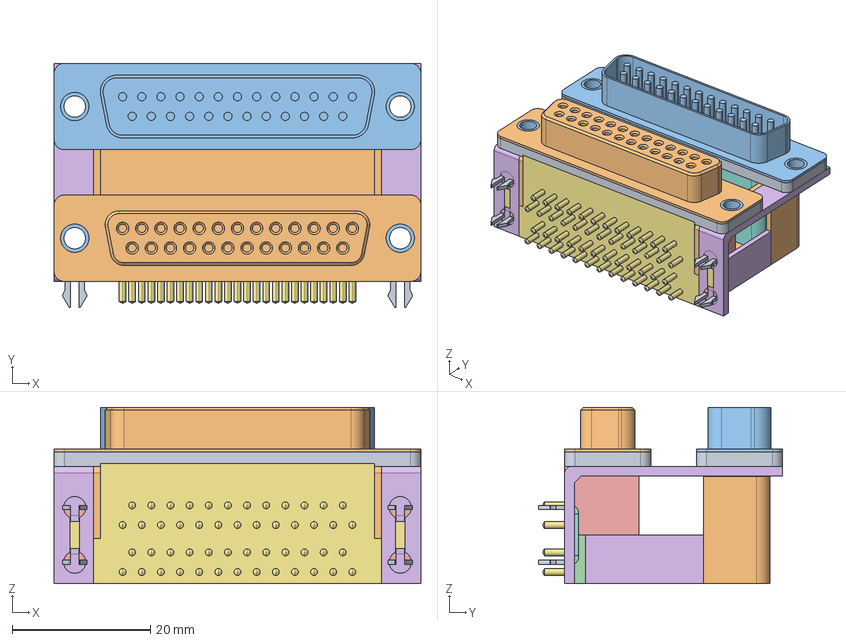
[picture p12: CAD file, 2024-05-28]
KiCAD/AmigaPCI Mainboard-KiCAD REV 60/AmigaPCI-Footprints/asub-277-25tp24.stp
53.1 x 35.3 x 25.5 mm

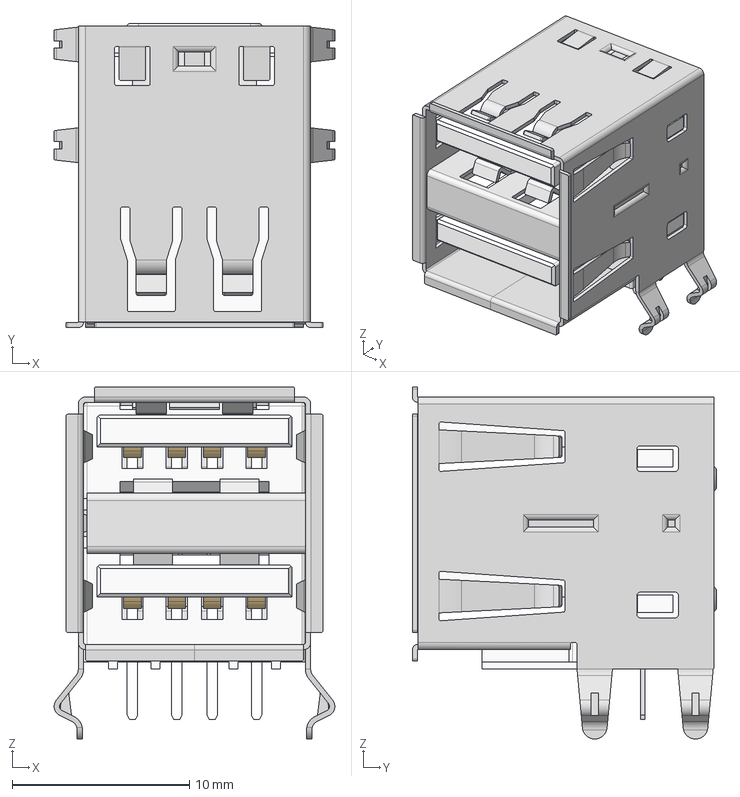
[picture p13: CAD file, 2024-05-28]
KiCAD/AmigaPCI Mainboard-KiCAD REV 60/AmigaPCI-Footprints/61400826021--3DModel-STEP-898076.STEP
15.8 x 17.1 x 19.8 mm
61400826021_Shielding1
61400826021_Housing
61400826021_Shielding2
61400826021_Pin2 x 4
61400826021_Pin1 x 4
61400826021_Shielding3

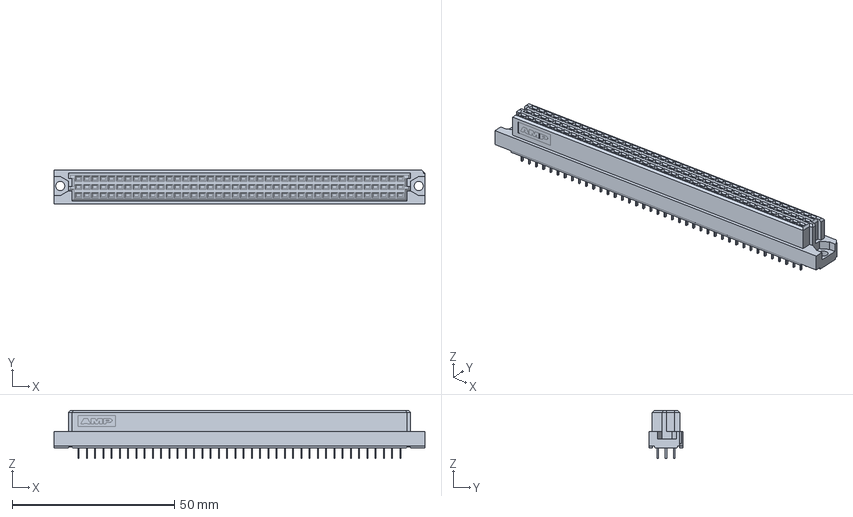
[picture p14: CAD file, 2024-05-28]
KiCAD/AmigaPCI Mainboard-KiCAD REV 60/AmigaPCI-Footprints/5535098-5.stp
114.2 x 10.6 x 14.8 mm

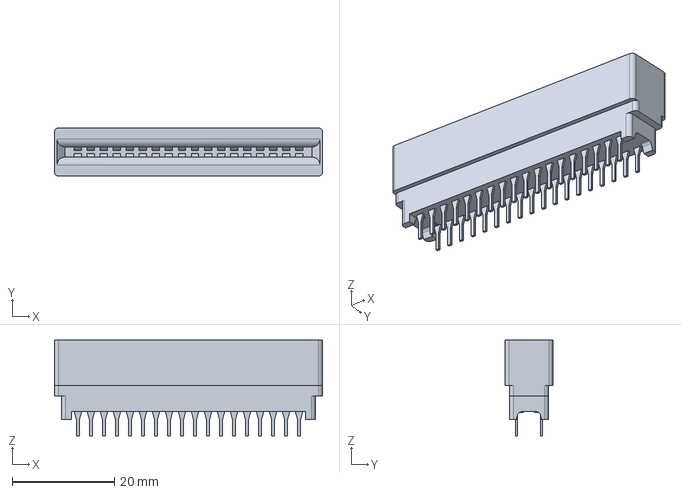
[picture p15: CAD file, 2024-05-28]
KiCAD/AmigaPCI Mainboard-KiCAD REV 60/AmigaPCI-Footprints/5530843-3.step
52.3 x 9.35 x 18.7 mm

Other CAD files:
KiCAD/AmigaPCI 68040 Local Bus Card Rev 41/AmigaPCI-Footprints/5145154-4.step
KiCAD/Dev/AmigaPCI Mainboard-KiCAD REV 40/AmigaPCI-Footprints/5145154-4.step
KiCAD/AmigaPCI Mainboard-KiCAD REV 60/AmigaPCI-Footprints/5145154-4.step
KiCAD/AmigaPCI Mainboard-KiCAD/AmigaPCI-Footprints/5145154-4.step
KiCAD/Dev/AmigaPCI 68040 Local Bus Card Rev 21/AmigaPCI-Footprints/5145154-4.step

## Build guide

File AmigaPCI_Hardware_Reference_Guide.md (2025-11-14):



<h1 align="center">AmigaPCI Hardware Reference Guide</h1>

<p align="center"><b>**THIS DOCUMENT IS A WORK IN PROGRESS AND IS SUBJECT TO CHANGE WITHOUT NOTICE.**</b></p>

<p align="center">For information on developing PCI hardware, see the <b>AmigaPCI PCI Hardware Developer Reference</b> guide.</p>

**Conventions**

1) Signals are presented as bold font, such as **_TS** or **TM2**.
2) A leading underscore (**_**) is indicates a signal is active low.
3) Examples of bus data are italicized, such as *DATA0* or *ADDRESS1*.  
4) Hex values are presented with a leading $ (dollar sign) and a space inserted every 4 characters for clarity.
5) AmigaPCI refers to this specification or any implementation of this specification, in part or whole.
6) CPU refers to the Motorola MC68040 or MC68060 processor, unless otherwise specified.

**Revision History**

THIS IS A DRAFT AND SUBJECT TO CHANGE WITHOUT NOTICE.

Revision|Date|Status
-|-|-

<p xmlns:cc="http://creativecommons.org/ns#" xmlns:dct="http://purl.org/dc/terms/"><a property="dct:title" rel="cc:attributionURL" href="https://github.com/jasonsbeer/AmigaPCI">AmigaPCI Hardware Reference Guide</a> by <a rel="cc:attributionURL dct:creator" property="cc:attributionName" href="https://github.com/jasonsbeer">Jason Neus</a> is licensed under <a href="https://creativecommons.org/licenses/by-nc/4.0/?ref=chooser-v1" target="_blank" rel="license noopener noreferrer" style="display:inline-block;">Creative Commons Attribution-NonCommercial 4.0 International</a></p>

---

# AmigaPCI

The AmigaPCI is a Motorola MC68040/MC68060 based OCS/ECS* Amiga computer in the ATX form factor. It provides a flexible local bus port, five AUTOCONFIG PCI slots compatable with Prometheus for expansion purposes such as video and sound, an on-board dual port ATA controller, and offers performance improvements over legacy Amiga designs.

*Original Chip Set and Enhanced Chip Set, respectively.

## 1. Overview

This document is an in-depth description of the architecture of the AmigaPCI system. Although all efforts have been made to make the document as complete and error-free as possible, it is presented AS-IS. No warranty or guarantee is made that the contents are valid for all use cases. This document assumes at least basic knowledge of Motorola, Amiga, and PCI architecture. This document introduces unique concepts, including specifications for AUTOCONFIG capable PCI devices. 

### 1.1 Processor

The AmigaPCI is intended to operate with the Motorola MC68040 or MC68060 processors. The processor is attached via the local bus port. See Sections 1.2.1 and 3.0.

### 1.2 Expansion Busses

The AmigaPCI includes expansion busses that allow for the user to expand the machine beyond its original capabilities.

#### 1.2.1 local bus Port

The AmigaPCI utilizes a local bus port to attach CPU devices to the AmigaPCI main board. The AmigaPCI has no CPU or fast RAM on the main board. Instead, the CPU and fast RAM is contained on a daughter card. This approach enables easier CPU upgrades with RAM logic suited to the specific processor and allows for inclusion of AUTOCONFIG devices on the Local Bus Card. See Section 2.0.

#### 1.2.2 PCI

The PCI bus is based on the PCI Local Bus Revision 2.3 specifications and is discussed in detail in the AmigaPCI PCI Hardware Developer Reference. All efforts are made to align implemented PCI features completely with the PCI Local Bus Revision 2.3. Discussion of implemented features will work exactly as detailed in the PCI Local Bus Revision 2.3 specifications.

#### 1.2.3 Video Slot

The AmigaPCI includes the Amiga 2000/3000 video bus. This allows for the use of OCS/ECS compatable video devices with the AmigaPCI.

### 1.3 Amiga Chipset

#### 1.3.1 Amiga Custom Chips

The AmigaPCI must be populated with the Amiga OCS/ECS chips shown in table 1.3.1. Reproductions in FPGA/CPLD may be used as well as the original equipment from Commodore. The Amiga chipset is required to enable critical functions of the Amiga computer.

Table 1.3.1 Amiga chipset.
Name|Chip ID|Commodore Part Number(s)|Quantity
-|-|-|-
Agnus|8372A or 8375||1
Denise|8362 or 8373||1
Paula|8364||1
CIA|8520A-1 or 8520PD|318029-03|2

#### 1.3.2 Kickstart ROMs

Kickstart ROMs for the Amiga 1200 should be burned to 100ns or faster 27C4096 EPROMs for use by the AmigaPCI. Original Amiga Kickstart Mask ROMs and EPROMs are not supported. 

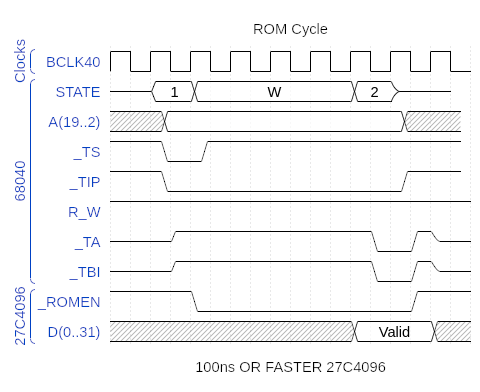
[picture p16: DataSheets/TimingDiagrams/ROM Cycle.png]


### 1.4 Floppy Disk Drives

The floppy disk interface is the primary way Amiga based computers store and retrieve external data. The AmigaPCI includes a header that supports two internal double density floppy disk drives. In the event two floppy disk drives (DF0 and DF1) are installed on the floppy disk drive header, J200 must have a jumper placed. When only one floppy disk drive is installed (DF0), there should be no jumper. See [Section 4.1](#41-floppy-disk-jumpers) for jumper settings.

In addition to supporting original Amiga floppy disk drives, the AmigaPCI supports floppy disk drives designed for the PC. An adaptation of Ian Steadman's PC floppy interface is implemented. Set the jumpers as shown in Table 1.4.2 depending on the type of floppy disk drives you are using. When using high density disk drives with high density floppy disks, it may be necessary to cover the high density hole with tape to prevent the disk drive from attempting to use the disk as high density, which is not supported by the Amiga chipset.

> [!NOTE]
> **You must use either Amiga disk drives or PC disk drives. Do not mix the two types.** 

### 1.5 ATA/ATAPI

The AmigaPCI includes two buffered, host terminated AUTOBOOT ATA ports for hard drives and ATAPI devices. Each ATA port supports two devices (master and slave) and is capable of 32-bit data transfer cycles. For instructions on installing and partitioning hard drives on the Amiga, refer to the [Commodore Hard Drive User's Guide](DataSheets/Hard_Drive_Users_Guide.pdf). This includes the HDToolBox user guide and other useful information for setting up both ATA and SCSI devices.

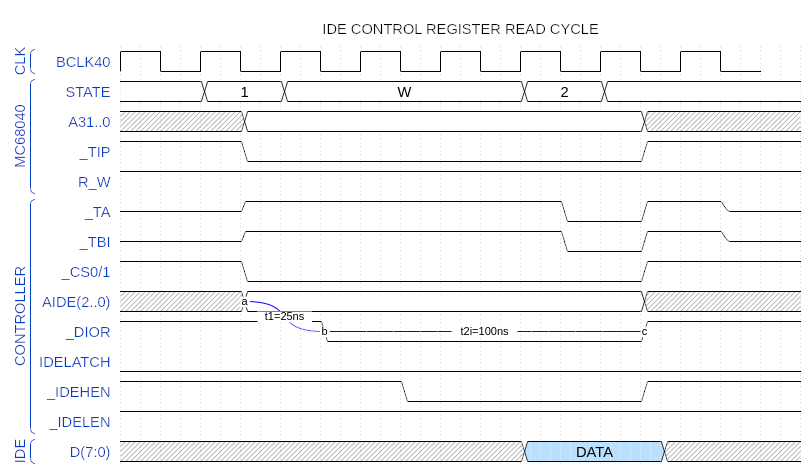
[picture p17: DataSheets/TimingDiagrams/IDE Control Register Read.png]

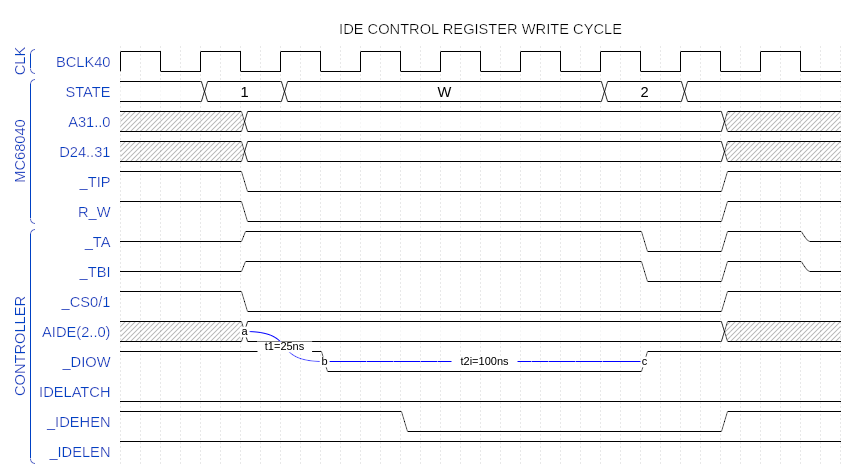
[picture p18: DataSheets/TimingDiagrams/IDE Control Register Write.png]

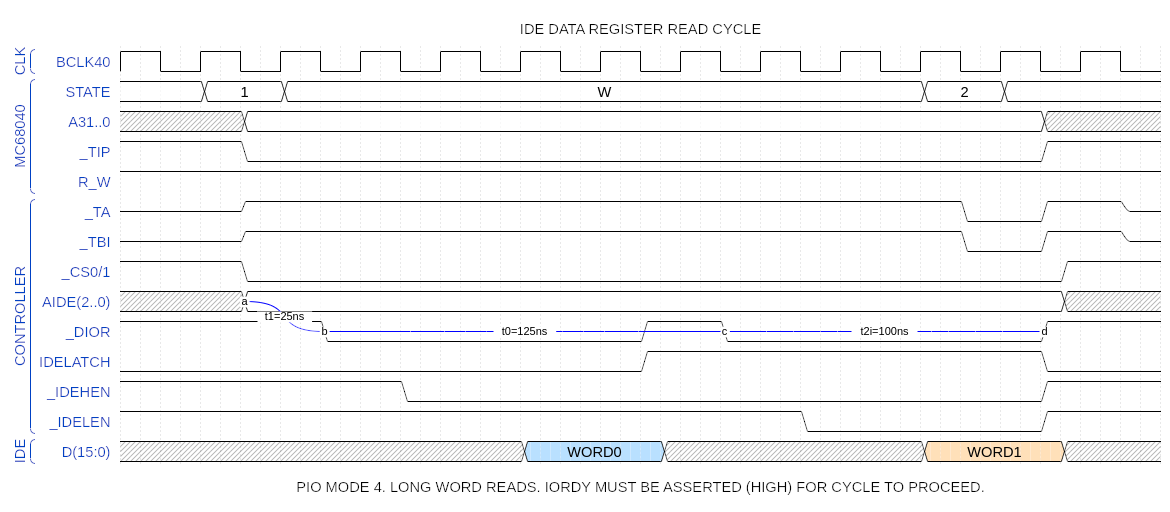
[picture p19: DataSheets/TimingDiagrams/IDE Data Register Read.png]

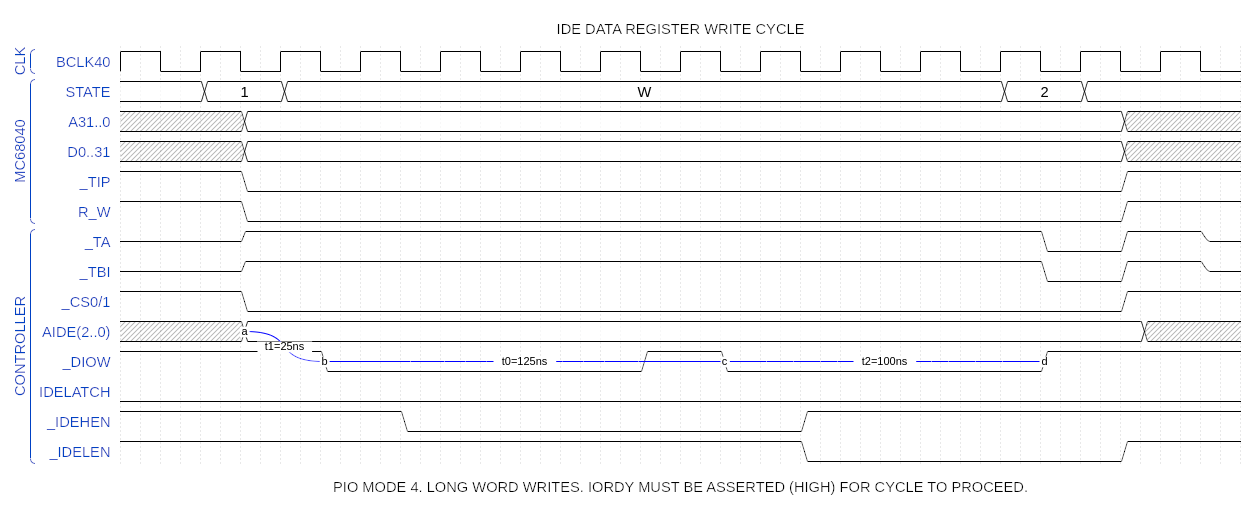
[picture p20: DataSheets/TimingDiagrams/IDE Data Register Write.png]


### 1.6 Human Interface Devices (HID)

The AmigaPCI support human interface devices (HID) via the two USB ports. Only keyboards and mice are supported. Support is supplied via the on-board STM32F205 microcontroller, which translates the HID inputs into Amiga compatable signals. The mouse HID signals are shared with the JOY1 port (see 1.8.4) via buffers. When there is active input from the HID mouse, the buffers are switched to only allow input from the HID port. When the HID mouse is not in active use, the buffers switch to allow input from JOY1. With this method, input from only one device is allowed at any time, with the mouse HID having priority.

### 1.7 Audio

The audio output is generated by Paula and run through the filter circuit as in the Amiga 4000. The audio output is supplied from a line level 3.5mm stereo jack. A CD audio header is included to support the input of analog line-level audio from optical drives or other devices. It is a 4-pin 2.54 pitch connector in the RGGL footprint, with pin 1 = R. This may be installed as a standard 4-pin male header or TE Connectivity part 5-103639-3, which is the MPC-2 locking header that has become ubiquitous. 

### 1.8 Legacy User Ports

#### 1.8.1 Parallel

The parallel port is a female DB25 connector, which is stacked with the serial male DB25 connector. The parallel port is completely compatable with legacy Amiga devices.

#### 1.8.2 Serial

The serial port is a male DB25 connector, which is stacked with the parallel female DB25 connector. The serial port is completely compatable with Amiga peripherals designed for the Amiga 500, 600, 1200, 2000, 3000, and 4000.

#### 1.8.4 Legacy Joystick and Mouse Ports

There are two legacy joystick port headers on the board. JOY1 is shared with the HID mouse input. In order to prevent signal contention with the HID mouse, the inputs from JOY1 are disconnected by a 74HCT4066 analog switch when the HID mouse is actively used. This prevents undesired behavior and allows only one device to input signals at a time, with the HID device having priority. See 1.6. The input for JOY2 is not shared with other devices. 

### 1.9 15KHz Video

The 15KHz standard Amiga video is output via an HD15 connector. This allows easy connection to converter boxes or any monitors that support the 15KHz standard. This connector only includes the signals needed for video output. Other signals present on the orignal Amiga video port are not included.

> [!NOTE] 
>Jumper J303 controls whether the H-Sync signal is driven by H-Sync or Copmposite Sync.

Signal|HD-15 Pin
-|-
Red|1
Green|2
Blue|3
H-Sync|13
V-Sync|14

### 1.10 Real Time Clock

The real time clock (RTC) of the AmigaPCI is supplied by the STM32F205 microcontroller. When the RTC address space is active, the board controller signals the microcontroller with the associated request. The microcontroller then consumes or supplies the necessary data. The microcontroller is connected to an external crystal to supply an accurate clock signal for the microcontroller. The crystal is adjustable via the trim capacitor VC200.

### 1.11 Flash ROM

The AmigaPCI has a two megabyte Flash ROM on board. The Flash ROM responds in one of four 512 kilobyte address spaces. The address spaces of the Flash ROM are scanned by Kickstart on startup, in the order shown, allowing modules to be executed at startup. This could include drivers for hardware devices on the AmigaPCI, Kickstart patches, or other software. If a valid ROM module header is found with a high enough priority, the entry will be added to the ROM tag list in RAM. The search then proceeds from the point immediately following the end of that module until the end of the region. Modules must be compiled in-place. The code may be position-independent, but the module header may not.

Flash ROM Block|Address Range
-|-
0|$00E0 0000 - $00E7 FFFF
1|$00A8 0000 - $00AF FFFF
2|$00B0 0000 - $00B7 FFFF
3|$00F0 0000 - $00F7 FFFF

## 2.0 Chipset Cycles

Functions that engage the chipset must follow the 7.16MHz timings of the timings of the Motorolla MC68000 (MC68000 herein) as implimented in the OCS/ECS Amiga designs.

#### 2.1 Chipset Register Cycles

The CPU accesses most chipset registers through Agnus. The chipset register cycle is as follows:

1) The CPU drives A1..20 in the chipset register address space and drives the data bus and R_W low for write cycles. The data bus bridge is tristate.
2) The CPU asserts _TS for one clock to indicate the start of a transfer. The register controller asserts _REGEN.
3) The register controller asserts _AS and _LDS, _UDS (for read cycles) during MC68000 State 2 (both C1 and C3 are low) and _LDS, _UDS during State 4 for write cycles.
4) On the rising edge of C1, Agnus drives a valid address on the chipset address (RGA) bus. 
5) On the falling edge of C1, the chipset drives valid data on the data bus (DRD) for read cycles or latches the data for write cycles.
6) On falling edge of C3 (rising edge of MC68000 State 6), the board controller latches the data bus on read cycles.
7) On the second falling edge of BCLK after entering MC68000 State 7, _TA and _TBI are asserted by the board controller to signal the MC68040 to complete the cycle and inhibit burst transfers.

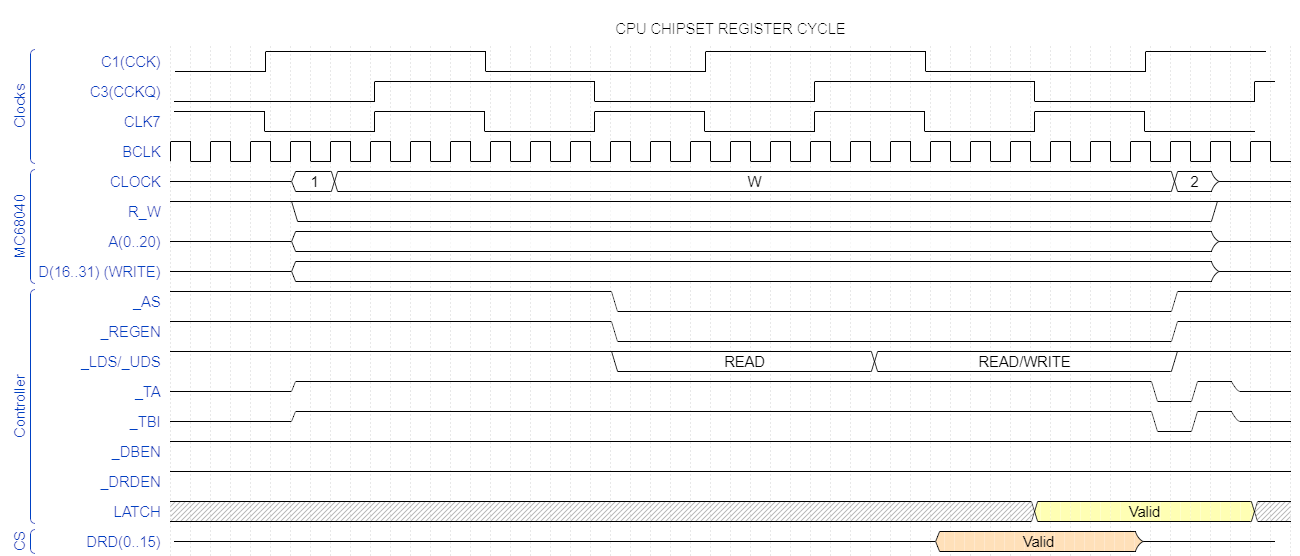
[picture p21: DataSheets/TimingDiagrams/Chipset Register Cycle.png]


#### 2.2 Chipset DMA Cycles

The Amiga chipset accesses the chipset RAM via direct memory access (DMA). The chipset accesses SDRAM as a 16-bit port. Because the AmigaPCI chipset SDRAM is a 32 bit port, the chipset data access is directed to either the low word or high word of the two words available by considering the Agnus column address DRA0 bit. The chipset DMA cycle does not adhear to the MC68000 bus transfer timing. The chipset DMA cycle spans two 7MHz clock cycles for writes and three 7MHz clock cycles for reads. The process is as follows:

1) The chipset asserts DMAL on the rising edge of C3 to request direct memory access (DMA).
2) Agnus asserts _DBR on the falling edge of C1 to indicate a chipset DMA cycle is in progress.
3) On the rising edge of C3, Agnus drives a valid row address on DRA0 - DRA9 and asserts _RAS0 or _RAS1. 
4) On the falling edge of C1, Agnus drives a valid column address on DRA0 - DRA9, asserts _CASL and _CASU, and drives _AWE low for write cycles. If DRA0 = 1, the data bridge is enabled and the data goes to the lower word of the SDRAM. When enabled, the data bridge direction is driven as the inverse of _AWE.
5) On the second falling edge of BCLK after Agnus asserts _CASU or _CASL, the RAM controller drives the _RAS address to the SDRAM with a bank activate command.
6) On the next falling edge of BCLK, the RAM controller drives the _CAS address to the SDRAM with a read or write command.
7) For read cycles, after any latency requirements, data is driven to the data bus by the SDRAM and latched by the chipset on the rising edge of C1. Write cycles are latched immediately with the _CAS command.

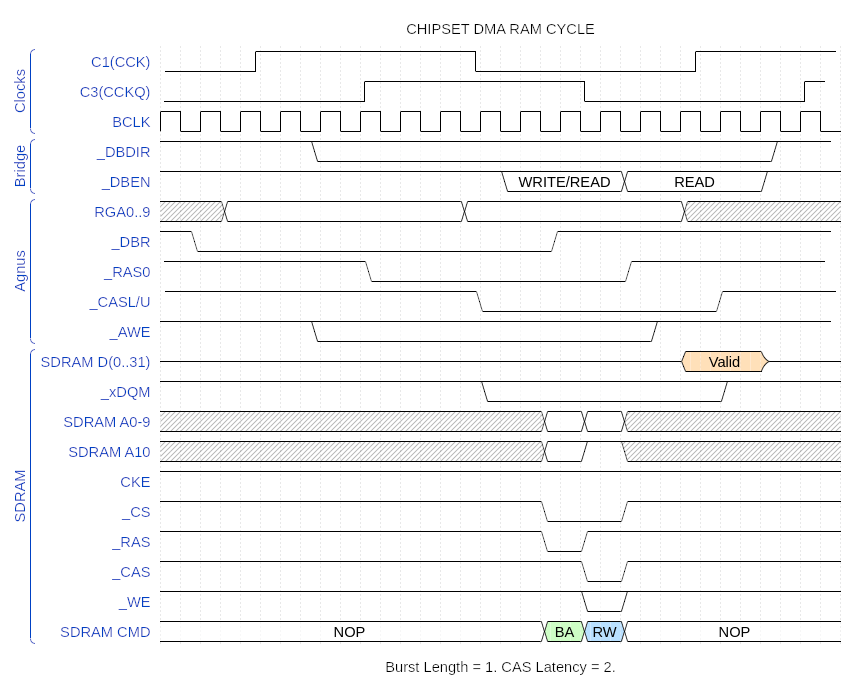
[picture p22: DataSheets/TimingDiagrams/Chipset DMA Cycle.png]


#### 2.3 CPU Chipset RAM Cycles

The CPU accesses the 32-bit chipset RAM independently of Agnus, which is a performance increase over original Amiga architecture. Chipset DMA transactions are given priority with the CPU capable of accessing the chipset RAM in between each DMA transfer cycle.

#### 2.4 CIA Cycles

The CIA clock is driven by the 28MHz Agnus clock as supplied by the on-baord oscillator. The clock is divided down to approximate the 1/10 7MHz clock found in original Amigas. Deriving the CIA clock this way prevents timing issues when a video device supplies its own system clock by asserting _XCLKEN.

#### 2.5 Cycle Timeout

Any time the CPU initiates a data transfer cycle by asserting _TS (transfer start), it expects the cycle to be acknowledged by assertion of _TA (transfer acknowledge). A fatal condition (crash) occurs when the CPU begins a cycle and does not receive acknowledgment from the target device. This would not normally happen, but can result from malfunctioning or poorly designed hardware. To prevent this situation, the board controller will assert _TACK  after 1400ns has passed from assertion of _TS. This allows the CPU to continue processing.

# 3.0 Local Bus Port

The AmigaPCI utilizes the Local Bus Port to attach CPU devices to the AmigaPCI main board. The AmigaPCI has no CPU on the main board. Instead, the CPU is contained on the Local Bus Card attached to this bus. This approach enables easier CPU upgrades and allows for inclusion of fast RAM and AUTOCONFIG devices on the Local Bus Card. Because the AmigaPCI main board has no Fast RAM, fast Ram must be included on the Local Bus Card. RAM can then be optimized for the clock speed and capabilities of the CPU device implemented. This enables an upgrade path for increased performance while minimizing resources needed on the AmigaPCI main board. A reference design can be found with the [AmigaPCI project](https://github.com/jasonsbeer/AmigaPCI/tree/main).

## 3.1 Devices

The primary purpose of the Local Bus Port is to provide a means to connect a MC68040, MC68060, or other compatable processor to the local bus of the AmigaPCI. There is no CPU on the AmigaPCI main board, so it will not function without a Local Bus Card attached. The Local Bus Port also supports other types of devices.

### 3.1.1 Fast Memory

The Amiga memory map reserves address range $0800 0000 - $0FFF FFFF for expansion fast memory. Any memory responding in this region will be automatically sized and added to the Amiga memory pool with the highest priority available. This address range is not part of the AUTOCONFIG space. On startup, this range is scanned from $0800 0000 and upward, 1MB ($0010 0000) at a time. RAM in this range must be located at $0800 0000 and higher to be detected.

### 3.1.2 AUTOCONFIG Devices

AUTOCONFIG devices may be added via the Local Bus Port by supplying the necessary AUTOCONFIG logic on the Local Bus Card. AUTOCONFIG devices on the Local Bus Port are always configured last. AUTOCONFIG devices on the local bus port must wait for assertion of _CPUCONF before attempting to configure.

## 3.2 Footprint and Connector

The local bus physical connector of the AmigaPCI is a DIN 41612 120 pin socket, 3 rows by 40 columns. The female (receptical) portion is on the AmigaPCI main board. The male (plug) portion is on the Local Bus Card. Examples of these connectors are part numbers 5535098-5 and 5650910-5 from TE Connectivity AMP Connectors. Specific footprint dimensions are not defined. The engineer may make the card any size they wish, within practical limits. The physical size must not extend outside the ATX specifications from the mounting point (not be larger than the AmigaPCI board). It must not interfere with the ATX power and ATA connectors and must not interfere with video cards or full size PCI plug in cards. In addition to the connector itself, there are two additional grounded mounting points to accomodate the Local Bus Card.

The origin datum and component points can be seen in Image 3.1. The origin of all measurements is the upper left mounting hole (datum = 0,0). The image is looking down on top of the card. The DIN connector is attached to the back of the card.

**Image 3.2**. Points from Datum 0,0 for the Local Bus Card.
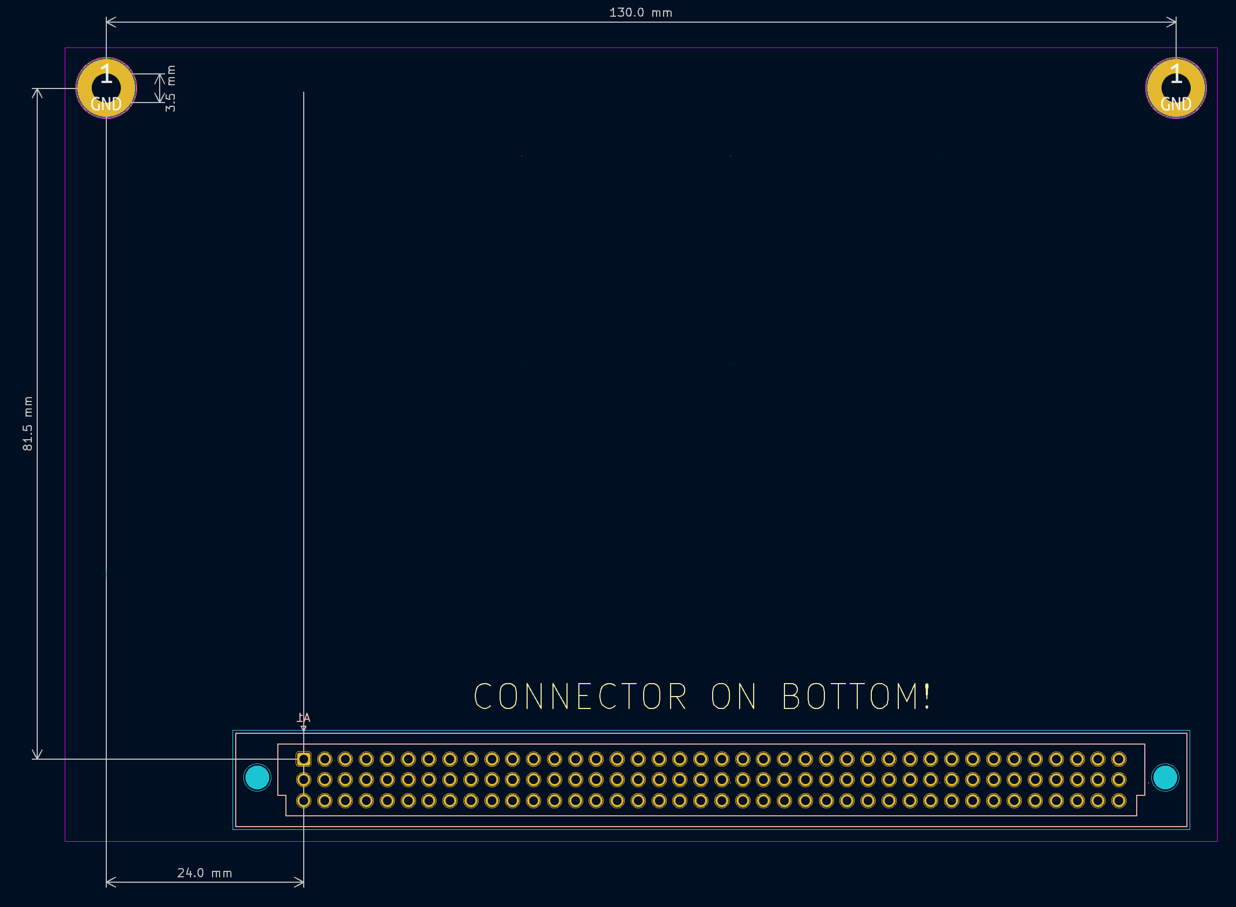
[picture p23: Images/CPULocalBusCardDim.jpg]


## 3.3 Bus Devices

The AmigaPCI local bus Port supplies signals to support master and target bus devices. Bus arbitration is handled by the arbitor on the AmigaPCI. The Local Bus Card may be a master, target, or both at once. The Local Bus Card may contain one or more target devices as well as one or more bus master devices.

### 3.3.1 Bus Master

Bus Master devices are devices that control the AmigaPCI while initiating data transfers between devices on the AmigaPCI. Only one bus master may control the system at any time. Most of the time, the CPU is the bus master. It is also possible for the PCI Bridge to become the bus master when a PCI device initiates a DMA transfer cycle. When asserted, **_BG** indicates to the CPU that it has control of the bus. When negated, either the PCI Bridge is the bus master or no device is the bus master. The bus master will assert bus busy (**_BB**) when actively driving the bus. **_BB** will be negated any time the bus master is not actively driving the bus. Holding **_BB** asserted unecessarily will prevent other devices from becoming the bus master. Unless the bus master has asserted bus lock (**_LOCK**), bus grant may be negated at any time. However, a new device must not take control of the bus until the bus busy (**_BB**) signal has been negated.

### 3.3.2 Target Device

A target device is any device that may be controlled by the bus master, such as memory or a drive controller. When addressed, the target device drives the data bus on reads, or latches the data on the data bus for writes. Each target device must terminate its cycles.

## 3.4 Local Bus Signals

The signals on the local bus Port are broken into categories. Some are specific to the MC68040/MC68060 and others are specific to the APCI. The signal descriptions are below. The flow of data (input/output/bidriectional) are defined from the perspective of the Local Bus Card. The pinout of the port is detailed in Table 3.4.

> [!WARNING] 
> **Applying TTL logic levels (+5V) to LVTTL only signals may damage devices on the AmigaPCI main board.**

### 3.4.1 Power

**GND** (Ground)  
This is the digital supply ground used by all digital devices in the system. Local Bus Cards may connect to ground through the connector and the mounting posts.

**+5VDC**  
This is the digital supply for TTL and TTL-like devices, such as F, LS, or HCT logic families and the Motorola MC68040.

**+3.3VDC**  
This is the digital supply for LVTTL devices, such as LVC logic families and the Motorola MC68060.

**+3.3VSB**
This always on power source is located on the local bus slot. Especially useful for I2C devices that may be used for wake-up functions. Only used for devices that require power when the system is otherwise powered off.

**+1.2VDC**  
This is the digital supply for low power devices of certain logic families or FPGA's, like the Lattice iCE40 series.

### 3.4.2 System Initialization

**_RESET** (System Reset) Input  
This LVTTL level signal is driven by the system reset logic and initiates a reset of all logic and I/O on the AmigaPCI and Local Bus Card, but not the CPU.

**_RSTOUT**  (Reset Out) Output  
This TTL tolerant signal is driven by the CPU to initiate a reset of all logic and I/O on the AmigaPCI and Local Bus Card, but not the CPU itself.

**CDONE** (Configuration Done) Output  
This LVTTL signal is driven by programmable logic devices (e.g. FPGA) on the Local Bus Card. When LOW, holds the entire system in reset until such time as all programmable logic devices on the AmigaPCI system have configured. In the absence of programmable logic devices, this may be left unconnected.

**_CPURST** (CPU Reset) Input  
This LVTTL signal is driven by the system reset logic and initiates a reset of the CPU. This signal is asserted in reponse to the push button or keyboard reset action.

### 3.4.3 Data Transfer Signals

**A(31..0)** (Address Bus) Bidirectional  
This bus is driven by the bus master and tristated by inactive bus masters. The local bus devices may drive this bus with either TTL or LVTTL level logic. However, the AmigaPCI drives this bus at TTL levels. As such, it is necessary that the Local Bus Card devices be TTL, TTL tolerant, or use level shifting to convert the incoming TTL levels to the voltage required.

**D(31..0)** (Data Bus) Bidirectional  
This bus is driven by the bus master for writes and the target device for reads and tristated by inactive bus masters. The local bus devices may drive this bus with either TTL or LVTTL level logic. However, the AmigaPCI drives this bus at TTL levels. As such, it is necessary that the Local Bus Card devices be TTL, TTL tolerant, or use level shifting to convert the incoming TTL levels to the voltage required.

**PORT** (Port Size) Input  
This LVTTL signal is driven by the target device and tristated by inactive target devices. Strictly address driven. Used to indicate the data bus width of the target device. Logic low (0) indicates a 32-bit port. Logic high (1) indicates a 16-bit port.

**R_W** (Read/Write) Bidirectional  
This TTL tolerant signal is driven by the bus master and tristated by inactive bus masters.

**SIZ(1..0)** (Transfer Size) Bidirectional  
This TTL tolerant bus is driven by the bus master and tristated by inactive bus masters. These are the MC68040/MC68060 transfer size signals. 

**_TACK** (Transfer Acknowledge) Bidirectional  
This LVTTL signal is driven by the target device and tristated by inactive target devices. Assertion indicates that the target device has completed the data transfer process for writes or has driven the data bus with the requested data for reads. Equivalent to the _TA signal.

**_TBI** (Tranfer Burst Inhibit) Input  
This LVTTL signal is driven by the target device and tristated by inactive target devices. Inhibits a burst cycle in favor of individual data transfers. Asserted with **_TACK**.

**_TCI** (Tranfer Cache Inhibit) Input  
This LVTTL signal is driven by the target device and tristated by inactive target devices. Inhibits caching of data from a data transfer burst cycle. Asserted with **_TACK**.

**_TEA** (Tranfer Error Acknowledge) Input  
This LVTTL signal is driven by the target device and tristated by inactive target devices. Asserted with **_TACK** to indicate a retry condition exists or asserted alone to indicate a cycle request cannot be completed (bus error).

**TT(1..0)** (Transfer Type) Bidirectional  
This TTL tolerant bus is driven by the bus master and tristated by inactive bus masters. These are the MC68040/MC68060 transfer type signals.

**TM(2..0)** (Transfer Modifiers) Bidirectional  
This TTL tolerant bus is driven by the bus master and tristated by inactive bus masters. These are the MC68040/MC68060 transfer modifier signals.

**_TS** (Transfer Start) Bidirectional  
This TTL tolerant signal is driven by the bus master and tristated by inactive bus masters. Indicates the start of a data transfer cycle.

### 3.4.4 Bus Arbitration Signals

**_BB** (Bus Busy) Bidirectional  
This TTL tolerant signal is driven by the bus master and tristated by inactive bus masters. Indicates the bus master is actively using the bus. This signal must not be unecessarily held asserted as that will prevent other devices from becoming bus masters.

**_BG** (Bus Grant) Input  
This LVTTL is asserted by the bus arbitor. Assertion indicates the CPU on the Local Bus Card has control of the system bus. Unless bus lock (**_LOCK**) has been asserted by the bus master, **_BG** may be negated at any time. Negation indicates either the PCI Local Bridge has the bus (with assedrtion of **_BB**) or no device has the bus (**_BB** is negated). A bus master must not take control of the system bus until **_BB** has been negated. When no device is actively requesting the bus, **_BG** is asserted.

**_BR** (Bus Request) Output  
This TTL tolerant signal is exclusively asserted by the CPU on the Local Bus Card to indicate a bus request. The CPU must not take control of the bus until it has been granted the bus by the assertion of **_BG** and the bus is not busy, as indicated by negation of **_BB**.

**_LOCK** (Bus Lock) Output  
This TTL tolerant signal is driven exclusively by the CPU, indicating a read-modify-write cycle is in progress. When asserted, prevents the bus arbitor from granting the bus to a new device.

### 3.4.5 Clocks

**BCLK** (Bus Clock) Output  
The 40MHz LVTTL bus clock is generated on the Local Bus Card and used to syncronize data transactions between the AmigaPCI and the local bus device.

### 3.4.6 Other local bus Port Signals

**_CPUCONF** (Local Bus Card Configure) Input  
This LVTTL signal is driven by logic on the AmigaPCI. It indicates AUTOCONFIG devices on the Local Bus Card may now be configured. AUTOCONFIG devices on the Local Bus Card are always configured last.

**_INT2** (Amiga Interupt 2) Output  
This TTL signal is driven by a target device on the Local Bus Card. Open drain.

**_INT6** (Amiga Interupt 6) Output
This TTL signal is driven by a target device on the Local Bus Card. Open drain.

**IPL(2..0)** (Interupt Level) Input  
This TTL bus is driven by the Amiga chipset.

**SDA** (I2C Serial Data) Bidirectional  
The I2C serial data signal is part of the I2C specification. This allows inclusion of I2C devices on the Local Bus Card.

**SCL** (I2C Serial Clock) Input  
The I2C serial clock is part of the I2C specification. This allows inclusion of I2C devices on the Local Bus Card.

**Table 3.4**. local bus Pinout.
Pin|Signal|Pin|Signal|Pin|Signal
-|-|-|-|-|-
**A1**|PORTSIZE|**B1**|_BB|**C1**|GND
**A2**|A12|**B2**|A13|**C2**|GND
**A3**|A14|**B3**|A0|**C3**|A15
**A4**|A1|**B4**|A2|**C4**|A3
**A5**|A4|**B5**|+3.3V|**C5**|+5V
**A6**|+1.2V|**B6**|+3.3V|**C6**|_INT2
**A7**|+5V|**B7**|GND|**C7**|_CPUCONF
**A8**|A6|**B8**|A5|**C8**|A9
**A9**|A8|**B9**|A7|**C9**|GND
**A10**|A11|**B10**|A10|**C10**|GND
**A11**|_BR|**B11**|_LOCK|**C11**|_CPURST
**A12**|TM0|**B12**|R_W|**C12**|TM1
**A13**|TM2|**B13**|D28|**C13**|+3.3V
**A14**|D26|**B14**|D24|**C14**|+3.3VSB
**A15**|D31|**B15**|D30|**C15**|D21
**A16**|D29|**B16**|D27|**C16**|SIZ0
**A17**|SIZ1|**B17**|_TS|**C17**|GND
**A18**|D20|**B18**|D22|**C18**|GND
**A19**|D25|**B19**|D19|**C19**|D23
**A20**|D17|**B20**|D15|**C20**|D14
**A21**|+3.3V|**B21**|_TACK|**C21**|_TEA
**A22**|+5V|**B22**|CDONE|**C22**|_BG
**A23**|_TBI|**B23**|_INT6|**C23**|_TCI
**A24**|GND|**B24**|D18|**C24**|D13
**A25**|+5V|**B25**|D16|**C25**|D12
**A26**|+5V|**B26**|D11|**C26**|D10
**A27**|D8|**B27**|D9|**C27**|_IPL0
**A28**|BCLK|**B28**|_RESET|**C28**|_IPL1
**A29**|GND|**B29**|_IPL2|**C29**|D7
**A30**|GND|**B30**|D6|**C30**|D5
**A31**|D2|**B31**|D4|**C31**|D1
**A32**|D0|**B32**|D3|**C32**|TT0
**A33**|+5V|**B33**|TT1|**C33**|SCL
**A34**|+3.3V|**B34**|SDA|**C34**|_RSTOUT
**A35**|A22|**B35**|A26|**C35**|A28
**A36**|A24|**B36**|A30|**C36**|A29
**A37**|GND|**B37**|A31|**C37**|A27
**A38**|GND|**B38**|A25|**C38**|A21
**A39**|A23|**B39**|A20|**C39**|A19
**A40**|A18|**B40**|A17|**C40**|A16

## 3.5 Signal Buffering

It is necessary to implement +5V tolerant tristate buffers on the data bus on the Local Bus Card. When the target device is on the Local Bus Card during a CPU driven cycle, it will be necessary to isolate the data bus on the Local Bus Card. This will prevent bus contention with the AmigaPCI data bus at the Local Bus Card connector. The buffers should remain enabled during PCI DMA cycles for target devices on the Local Bus Card.

## 3.6 Clocks

The bus clock (BCLK) is a 40MHz clock that is used to time data transer cycle responses to the Local Bus Card. The 40MHz bus clock is generated on the Local Bus Card. This minimizes issues with clock skew where the Local Bus Card may have high-speed RAM or other timing sensitive devices. BCLK is unbuffered and routed to U712 on the AmigaPCI. The signal is then distributed to other FPGA's on the AmigaPCI via a PLL in U712.

Correct clock distribution is critical to ensure stable operation of the Local Bus Card and AmigaPCI. Each clocked device should have a dedicated clock signal by using fanouts from a singal clock source. Traces should be kept as short as possible and small value series resistors should be implemented at the clock signal source.

## 3.7 Cycle Termination

The Local Bus Card must support dynamic bus sizing to enable the 16-bit data ports of the Amiga chipset. The AmigaPCI supplies two data cycle termination signals, **PORTSIZE** and **_TACK**. **PORTSIZE** is an address driven signal indicating the data port width of the device currently addressed. A logic low signal indicates the addressed data port is 32-bits wide, while a logic high signal indicates a 16-bit port. **_TACK** is asserted by the AmigaPCI logic to indicate the completion of a data transfer cycle of any port size and is latched on the rising edge of **BCLK**. Together, these signals are used to determine the status of the current data transfer cycle. The AmigaPCI implements 16-bit and 32-bit data ports. Support of 8-bit target devices is not necessary.

If the data width to be transfered is greater than the data port width of the addressed device, multiple transfer cycles are required to complete the data transfer. For example, if the MC68040/MC68060 initiates a long-word transfer and the target device responds as a 16-bit port, the dynamic bus sizer will latch the 16 bits of the first cycle, increment the address, and run a second cycle to latch the next 16 bits. These two cycles are driven by the dynamic bus sizer and are transparent to the MC68040/MC68060. Once the dynamic bus sizer latches all the requested data on a read cycle, or completes the necessary cycles on a write, it asserts **_TA** to signal the MC68040/MC68060 to complete the cycle. The dynamic bus sizer places the most significant byte of the transfer at D31-24. The next most significant at D23-16. Misaligned operands are treated the same, with the byte enable signals identifying the particular byte(s) to be latched.

Dynamic bus sizing is described in great detail in the [Motorola MC68030](/DataSheets/Motorola/MC68030UM.pdf) user manual, Sections 7.2.1-7.2.3, and the [MC68040 Designer's Handbook](/DataSheets/Motorola/MC68040_Designers_Handbook_1990.pdf), Section 7. It is strongly advised to review these documents, as significant reproduction here is not attempted. A reference project can be found with the MC68040 Local Bus Card with the [AmigaPCI project Github repo](https://github.com/jasonsbeer/AmigaPCI).

Figure 3.7 shows a state machine for enabling dynamic bus sizing. This state machine is adapted from Section 7 of the MC68040 Designer's Handbook from Motorola. 

Figure 3.7.  
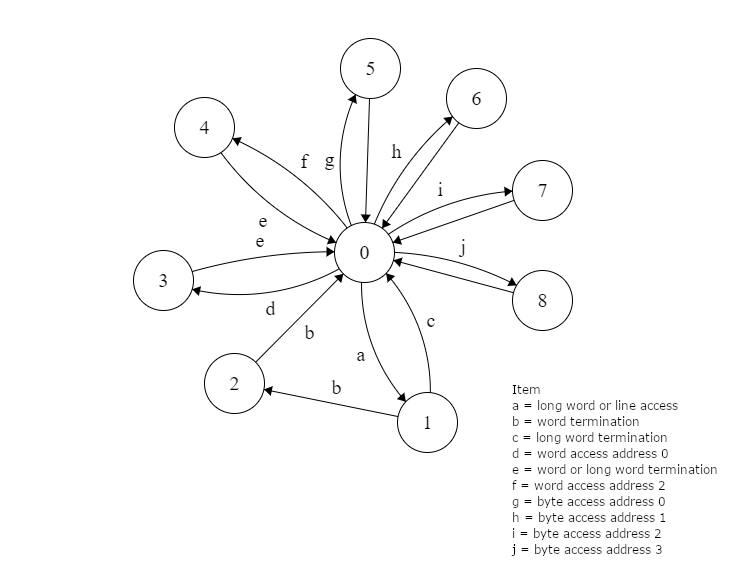
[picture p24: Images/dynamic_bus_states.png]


# 4.0 Jumpers

There are a number of jumpers on the AmigaPCI mainboard that control how it behaves. Incorrect jumper settings can lead to system instability or failure to boot.

### 4.1 Floppy Disk Jumpers

Description|Jumper|Setting|Result
-|-|-|-
DF1 Presence|J200|Short|Second internal floppy drive present.
[]()|[]()|Open|Second internal floppy drive not present.
Floppy Disk Change Signal|J201|1-2 Amiga|Amiga type floppy drive(s) installed.
[]()|[]()|2-3 PC|PC type floppy drive(s) installed.
Floppy Ready Signal|J202|1-2 Amiga|Amiga type floppy drive(s) installed.
[]()|[]()|2-3 PC|PC type floppy drive(s) installed.

> [!NOTE]
> Jumpers J201 and J202 must be set to PC Type or Amiga Type. It is not possible to mix the drive types.

### 4.2 Agnus Jumpers

Description|Jumper|Setting|Result
-|-|-|-
Agnus Part|J204|Short|Agnus 8372A Installed.
[]()|[]()|Open|Agnus 8375 Installed.
Agnus Video Mode|J205|Short|PAL 8375 Installed.
[]()|[]()|Open|NTSC 8375 or any 8372A Installed.
Agnus Vbb|J206|1-2 Vbb|Agnus 8375 Vbb Only.
[]()|[]()|2-3 Non-Vbb|Agnus 8372A and 8375 non-Vbb.
Agnus Data/GND|J210|Short|Agnus 8372A Installed.
[]()|[]()|Open|Agnus 8375 Installed.

> [!NOTE]
> Agnus 8372A is capable of either PAL or NTSC operation.  
> Agnus 8375 are PAL or NTSC specific by part number.

### 4.3 TICK Jumpers

Description|Jumper|Setting|Result
-|-|-|-
TICK Frequency|J207|1-2 50Hz|PAL
[]()|[]()|2-3 60Hz|NTSC
Timebase Source|J208|1-2 VSYNC|Timebase driven by Agnus VSYNC.
[]()|[]()|2-3 TICK|Timebase driven by TICK.

### 4.4 STM Microcontroller Jumpers

Description|Jumper|Setting|Result
-|-|-|-
STM Boot Mode|J209|1-2 Program|Program microcontroller via USB port.
[]()|[]()|2-3 Run|Factory default.
Clock Calibrate|J210|Short|Factory Default.
[]()|[]()|Open|Pin 2 used to calibrate clock crystal frequency.

### 4.5 Video Jumpers

Description|Jumper|Setting|Result
-|-|-|-
Sync Source|J303|1-2 HSYNC|Supplies HSYNC to pin 13 of the HD15 video port.
[]()|[]()|2-3 CSYNC|Supplies CSYNC to pin 13 of the HD15 video port.

### 4.6 ATA Jumpers

Description|Jumper|Setting|Result
-|-|-|-
ATA Autoboot|J900|Short|ATA autoboot disabled.
[]()|[]()|Open|ATA autoboot enabled.
Primary PIO Mode|J901|Short|PIO2
[]()|[]()|Open|PIO4
Secondary PIO Mode|J902|Short|PIO2
[]()|[]()|Open|PIO4

### 4.7 ROM Wait State Jumpers

Description|Jumper|Pin 1-2|Pin 3-4|Result
-|-|-|-|-
ROM Wait States|J212|Open|Open|250ns
[]()|[]()|Short|Open|200ns
[]()|[]()|Open|Short|150ns
[]()|[]()|Short|Short|100ns

### 4.8 Reserved Jumpers

Reserved jumpers are for future use. Do not place jumpers at these locations.  

Description|Jumper|Setting|Result
-|-|-|-
RESERVED|J100|[]()|
RESERVED|J101|[]()|
RESERVED|J102|[]()|
RESERVED|J203|[]()|

# Appendix A - AmigaPCI Memory Map

The AmigaPCI memory map is a modification of the Amiga 1200 memory map. Some of the address space implemented occupies the Gayle PCMCIA register spaces. Gayle-like PCMCIA devices must not be added to the AmigaPCI.

Address Start|Address End|Description
-|-|-
$0000 0000|$001F FFFF|Amiga Chip Memory
$0020 0000|$009F FFFF|Zorro 2 Memory Expansion Space
$00A0 0000|$00A7 FFFF|Zorro 2 I/O Expansion Space
$00A8 0000|$00AF FFFF|Flash Memory Block 0
$00B0 0000|$00B7 FFFF|Flash Memory Block 1
$00B8 0000|$00BE FFFF|Reserved
$00BF 0000|$00BF FFFF|CIA Ports and Timers
$00C0 0000|$00DB FFFF|Reserved
$00DB 0000|$00DB FFFF|ATA Registers
$00DC 0000|$00DC FFFF|Real Time Clock
$00DD 0000|$00DE FFFF|Reserved
$00DF 0000|$00DF FFFF|Chipset Registers
$00E0 0000|$00E7 FFFF|Flash Memory Block 2
$00E8 0000|$00E8 FFFF|AUTOCONFIG Configuration Registers
$00E9 0000|$00EF FFFF|Zorro 2 I/O Expansion Space
$00F0 0000|$00F7 FFFF|Flash Memory Block 3
$00F8 0000|$00FF FFFF|ROM
$0100 0000|$07FF FFFF|Reserved
$0800 0000|$0FFF FFFF|Local Bus Port RAM
$1000 0000|$7FFF FFFF|32-Bit Memory Expansion Space
$8000 0000|$9FFF FFFF|PCI Register and Memory Expansion Space
$A000 0000|$FFFF FFFF|Reserved

**END**

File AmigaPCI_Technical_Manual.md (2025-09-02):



<h1 align="center">AmigaPCI Hardware Reference</h1>

<p align="center">"If I have seen further, it is by standing on the shoulders of giants."<br>-Sir Isaac Newton</p>

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

**Conventions**

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

**Revision History**

THIS IS A DRAFT AND SUBJECT TO CHANGE WITHOUT NOTICE.

Revision|Date|Status
-|-|-

<p xmlns:cc="http://creativecommons.org/ns#" xmlns:dct="http://purl.org/dc/terms/"><a property="dct:title" rel="cc:attributionURL" href="https://github.com/jasonsbeer/AmigaPCI">AmigaPCI Hardware Reference</a> by <a rel="cc:attributionURL dct:creator" property="cc:attributionName" href="https://github.com/jasonsbeer">Jason Neus</a> is licensed under <a href="https://creativecommons.org/licenses/by-nc/4.0/?ref=chooser-v1" target="_blank" rel="license noopener noreferrer" style="display:inline-block;">Creative Commons Attribution-NonCommercial 4.0 International</a></p>

---

# AmigaPCI

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

*Original Chip Set and Enhanced Chip Set, respectively.

## 1. Overview

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

### 1.1 Processor

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

### 1.2 Expansion Busses

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

#### 1.2.1 local bus Port

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

#### 1.2.2 PCI

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

#### 1.2.3 Video Slot

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

### 1.3 Amiga Chipset

#### 1.3.1 Amiga Custom Chips

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

#### 1.3.2 Kickstart ROMs

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



### 1.4 Floppy Disk Drives

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

### 1.5 ATA/ATAPI

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

### 1.6 Human Interface Devices (HID)

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

### 1.7 Audio

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

### 1.8 Legacy User Ports

#### 1.8.1 Parallel

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

#### 1.8.2 Serial

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

#### 1.8.4 Legacy Joystick and Mouse Ports

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

### 1.9 15KHz Video

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

Signal|HD-15 Pin
-|-
Red|1
Green|2
Blue|3
H-Sync|13
V-Sync|14

### 1.10 Real Time Clock

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

### 1.11 Flash ROM

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

## 2.0 Chipset Cycles

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

#### 2.1 Chipset Register Cycles

The CPU accesses most chipset registers through Agnus. The chipset register cycle is as follows:

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



#### 2.2 Chipset DMA Cycles

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



#### 2.3 CPU Chipset RAM Cycles

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

#### 2.4 CIA Cycles

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

#### 2.5 Cycle Timeout

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

# 3.0 Local Bus Port

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

## 3.1 Devices

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

### 3.1.1 Fast Memory

The Amiga memory map reserves the address ranges $0400 0000 - $07FF FFFF and $0800 0000 - $0FFF FFFF for fast memory. These two regions are treated differently by Kickstart. Any memory responding in these regions will be automatically sized and added to the Amiga memory pool with the highest priority available. These address ranges are fixed and are not part of the AUTOCONFIG space. 

#### 3.1.1.1 Address Range $0400 0000 - $07FF FFFF

On startup, this range is scanned from $07F0 0000 and downward, 1MB ($0010 0000) at a time. RAM in this range must be located at $07F0 0000 and lower to be detected. This area is not automatically scanned by the A1200 Kickstart ROM.

#### 3.1.1.2 Address Range $0800 0000 - $0FFF FFFF

On startup, this range is scanned from $0800 0000 and upward, 1MB ($0010 0000) at a time. RAM in this range must be located at $0800 0000 and higher to be detected. This area is automatically scanned by the A1200 Kickstart ROM.

### 3.1.2 AUTOCONFIG Devices

AUTOCONFIG devices may also be added via the Local Bus Port by supplying the necessary AUTOCONFIG logic on the Local Bus Card. AUTOCONFIG devices on the Local Bus Port are configured first. Once the devices on the Local Bus Card are configured, the **_CPUCONF** signal must be asserted. Failure to do so will prevent other devices on the AmigaPCI from being configured. AUTOCONFIG devices must terminate the data transfer cycle when the AUTOCONFIG device is addressed.

## 3.2 Footprint and Connector

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

## 3.3 Bus Devices

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

### 3.3.1 Bus Master

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

### 3.3.2 Target Device

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

## 3.4 Local Bus Signals

The signals on the local bus Port are broken into categories. Some are specific to the MC68040/MC68060 and others are specific to the APCI. The signal descriptions are below. The flow of data (input/output/bidriections) are defined from the perspective of the local bus car. The pinout of the port is detailed in Table 3.4.

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

### 3.4.1 Power

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

### 3.4.2 System Initialization

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

### 3.4.3 Data Transfer Signals

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

### 3.4.4 Bus Arbitration Signals

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

### 3.4.5 Clocks

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

### 3.4.6 Other local bus Port Signals

**_CPUCONF** (Local Bus Card Configured) Output  
This LVTTL signal is driven by AUTOCONFIG logic on the Local Bus Card. Indicates AUTOCONFIG devices on the Local Bus Card have been configured. AUTOCONFIG devices on the Local Bus Card are configured first. Once configured, asserting this signal allows devices on the AmigaPCI main board to be configured. In the absence of an AUTOCONFIG device, this may be left unconnected

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

**IPL(2..0)** (Interupt Level) Input  
This TTL bus is driven by the Amiga chipset.

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

## 3.5 Signal Buffering

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

## 3.6 Clocks

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

## 3.7 Cycle Termination

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

Figure 3.7.  


# 4.0 Jumpers

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

### 4.1 Floppy Disk Jumpers

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

### 4.2 Agnus Jumpers

Description|Jumper|Setting|Result
-|-|-|-
_RAMEN|J203|Short|Pass the _RAMEN signal to Agnus.
[]()|[]()|Open|Do not pass the _RAMEN signal to Agnus. Factory Default.
Agnus Part|J204|Short|Agnus 8372A Installed.
[]()|[]()|Open|Agnus 8375 Installed.
Agnus Video Mode|J205|Short|PAL 8375 Installed.
[]()|[]()|Open|NTSC 8375 or any 8372A Installed.
Agnus Vbb|J206|1-2 Vbb|Agnus 8375 Vbb Only.
[]()|[]()|2-3 Non-Vbb|Agnus 8372A and 8375 non-Vbb.
Agnus Data/GND|J210|Short|Agnus 8372A Installed.
[]()|[]()|Open|Agnus 8375 Installed.

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

### 4.3 TICK Jumpers

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

### 4.4 STM Microcontroller Jumpers

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

### 4.5 Video Jumpers

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

### 4.6 ATA Jumpers

Description|Jumper|Setting|Result
-|-|-|-
ATA Autoboot|J900|Short|ATA autoboot disabled.
[]()|[]()|Open|ATA autoboot enabled.

### 4.7 Reserved Jumpers
Description|Jumper|Setting|Result
-|-|-|-
RESERVED|J100|[]()|
RESERVED|J101|[]()|
RESERVED|J102|[]()|
RESERVED|J901|[]()|
RESERVED|J902|[]()|

**END**

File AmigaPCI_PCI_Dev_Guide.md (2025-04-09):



<h1 align="center">PCI Hardware Developer Reference</h1>

<p align="center">"If I have seen further, it is by standing on the shoulders of giants."<br>-Sir Isaac Newton</p>

**Disclaimer**

This document defines how the PCI Local Bus Rev. 2.3 specification is implemented in the AmigaPCI. It is not a substitute for the PCI Local Bus Specification or relevant Motorola user manuals. It is expected the reader has reviewed and understands the tenants of the PCI Bus as defined in the PCI Local Bus Specification, Rev 2.3, and the relevant Motorola user manuals.

This document is a work in progress and is presented "as-is" with no waranty expressed or implied.

<p align="center"><b>**THIS DOCUMENT IS A WORK IN PROGRESS AND IS SUBJECT TO CHANGE WITHOUT NOTICE.**</b></p>

**Conventions**

1) Signals are presented as bold font, such as **_FRAME** or **_TA**.
2) A leading underscore (**_**) indicates a signal is active low.
3) Examples of bus data are italicized, such as *DATA0* or *ADDRESS1*.  
4) Hex values are presented with a leading 0x and a space inserted every 4 characters for clarity.
5) AmigaPCI refers to this specification or any implementation of this specification, in part or whole.
6) CPU refers to the Motorola MC68040 or MC68060 processor, unless otherwise specified.
</br>

**Revision History**  
Revision|Date|Status
-|-|-
0.0|xx|FIRST DRAFT
</br>
<p xmlns:cc="http://creativecommons.org/ns#" xmlns:dct="http://purl.org/dc/terms/"><a property="dct:title" rel="cc:attributionURL" href="https://github.com/jasonsbeer/AmigaPCI">AmigaPCI PCI Hardware Developer Reference</a> by <a rel="cc:attributionURL dct:creator" property="cc:attributionName" href="https://github.com/jasonsbeer">Jason Neus</a> is licensed under <a href="https://creativecommons.org/licenses/by-nc/4.0/?ref=chooser-v1" target="_blank" rel="license noopener noreferrer" style="display:inline-block;">Creative Commons Attribution-NonCommercial 4.0 International</a></p>

---

# 1.0 PCI Bus

The PCI Local Bus (PCI, herein) is a processor independent, 32-bit expasion bus. The AmigaPCI specification is designed to comply with the PCI Local Bus Revision 2.3 specificiation. Each slot supports Universal and 5V cards, as defined in the PCI Local Bus Revision 2.3 specification. Like Zorro 2 and Zorro 3, PCI supports auto configuration of devices on power up. This allows for the use of Amiga AUTOCONFIG to configure devices at start up. This fits well with Amiga OS as PCI devices can be configured as Zorro 3 devices, which function natively with Amiga OS. 

The PCI Bridge is implemented via a Motorola MC68040/MC68060 to PCI Bridge (Local PCI Bridge, herein). The Local PCI Bridge logic translates data requests from the Motorola processor and PCI devices in order that they may communicate. This specification is compatable with Motorola MC68040 and newer predecessors. While this document is written with the Motorola MC68040 in mind, the information can be applied to newer Motorola processors, such as the MC68060.

Each PCI slot on the PCI Local Bridge can operate in either AUTOCONFIG mode or Prometheus mode, but not both simultaneously. 

## 1.1 Endianness

Motorola MC68000 series processors are big endian devices. PCI devices, by contrast, are little endian devices. This means we must byte swap the data signals to provide compatability between devices with different endianness*. The AmigaPCI specification implements address invariance to achieve the endian conversion necessary for the CPU and PCI devices to communicate.

Table 1.1a. Order of byte consumption in big and little endian devices.
Endianess|Hex Value<br />Order of Consumption
-|-
&nbsp;|0x0002 0804
Big| START---->
Little| <----START

The smallest unit of data considered by the PCI specification is one byte. With this consideration, data bytes are swapped to accomodate the conversion in endianess. This byte swapping is implemented in the AmigaPCI Local PCI Bridge hardware.

Table 1.1b. Byte swapping between big and little endian devices.
Endianess|Hex Value|Address 0x00|Address 0x01|Address 0x02|Address 0x03
-|-|-|-|-|-
Big|0x0002 0804|0x00|0x02|0x08|0x04
Little|0x0408 0200|0x04|0x08|0x02|0x00

*Application Note AN2285. Data Movement Between Big-Endian and Little-Endian Devices. Rev 2.2. Freescale Semiconductor. 2008

## 1.2 Interrupt Handling

Each PCI slot has four interrupt signals, identified as **_INTA**, **_INTB**, **_INTC**, and **_INTD**. Single function PCI devices are only allowed to use **_INTA**. The remaining signals are used in the event of a multifunction PCI device, with one interrupt line per PCI function. As a hyptothetical example, a multifunction I/O device may use **_INTA** for a floppy drive interface, **_INTB** for a hard drive interface, **_INTC** for a serial interface, etc. For the purposes of the AmigaPCI design, **_INTA**, **_INTB**, **_INTC**, and **_INTD** are OR'd together and connected to **_INT2**. Drivers are expected to look for assertion of **_INT2** to signal an interrupt request from devices on the PCI bus. When an interrupt is asserted, the driver needs to poll its device on the PCI bus to determine if its device is asserting the interrupt. The Local PCI Bridge will continue to assert **_INT2** until all PCI devices have negated their interrupt requests. 

## 1.3 Modes of Operation

Amiga PCI slots can operate in AUTOCONFIG mode or Prometheus compatable mode. Each individual PCI slot may operate in one of these modes, but never both simultaneously.

In AUTOCONFIG mode, the PCI target device will be configured on startup like any Amiga AUTOCONFIG device. The advantage of AUTOCONFIG mode is the ability to use a PCI device upon startup without the need to load drivers from disk. This supports devices such as auto booting hard drives, video, sound cards, etc. Once the PCI target device is configured by the AUTOCONFIG process, the target device may be directly accessed by its base address(es). 

Prometheus mode requires the PCI target device be configured in software in order to function. This mode can support PCI target devices not designed for the Amiga. During startup, the Local PCI Bridge is configured via AUTOCONFIG in the 32-bit Zorro 3 address space, which will supply a base address for the Local PCI Bridge through which the slots in Prometheus mode may be accessed. Driver software may then poll the Local PCI Bridge base address with each device selection bit. The Local PCI bridge will return 0xFFFF FFFF if an AUTOCONFIG slot is polled via the Local PCI Bridge base address. 

## 1.4 Developing PCI Cards for the AmigaPCI and Upgrade Path

New PCI hardware developed specifically for the AmigaPCI should be based on specifications for the Universal* PCI card. Should demand justify it, future upgrade options may include the move to a 3.3V signaling environment capable of running at 66MHz**. Plug in hardware based on the Universal concept will permit cards to work in either 5V or 3.3V signaling environments. In addition, any hardware developed for the AmigaPCI must limit address spaces to Memory and Configuration only. The I/O address space is not recommended for new hardware development*** and is not supported by the AmigaPCI with AUTOCONFIG devices.  

*PCI Local Bus Specification Revision 2.3. PCI Special Interest Group. Section 4.1.1. Transition Road Map. pp. 113.  
**PCI Local Bus Specification Revision 2.3. PCI Special Interest Group. Section 7.6.3. Signaling Environment. pp. 230.  
***PCI Local Bus Specification Revision 2.3. PCI Special Interest Group. Section 3.2.2. Addressing. pp. 27.  

# 2.0 PCI Configuration

Each PCI target device may be configured by the Amiga AUTOCONFIG process or by software configuration (Prometheus). During configuration, each PCI slot in turn, is polled to obtain the capabilities and address space needs of the target device. Each PCI slot is polled by asserting the **IDSEL** signal, which is approximately equivalent to the **_CFGIN** signal of the Zorro bus. However, unlike the **_CFGIN** signal, the **IDSEL** is asserted by a specific address bit during the address phase of a configuration command access*. Because the Local PCI Bridge addresses each slot directly, as opposed to the fall through system of Zorro, there is no equivalent, or need, of a **_CFGOUT** signal.

*PCI Local Bus Specification Revision 2.3. PCI Special Interest Group. Section 3.2.2.3.5. System Generation of IDSEL. pp. 36-37.

## 2.1 Local PCI Bridge

The Local PCI Bridge is always configured via the AUTOCONFIG process at startup before other PCI devices. The Local PCI Bridge base address allows direct access of the Local PCI Bridge configuration registers and a means to access Prometheus configured PCI cards on the PCI bus (See 2.3  Prometheus Configuration). All PCI devices are accessed through the Local PCI Bridge, which acts as an interface between the devices on the CPU bus and devices on the PCI bus. The Local PCI Bridge also handles bus arbitration. During each CPU data transfer cycle, the address information is broadcast by the Local PCI Bridge to the PCI bus. If any devices respond by asserting **_DEVSEL**, the Local PCI Bridge proceeds with the PCI cycle. Otherwise, the Local PCI Bridge returns to an idle state.

The following 16-bit registers are available on the Local PCI Bridge device. All registers can be read. This allows polling of the Local PCI Bridge settings and status. Reading a long word at offset 0x04 will return both registers. Accessing the registers from the MC68040 will result in big endian ordering of the bytes. Accessing the registers from the PCI bus will result in little endian ordering. Reads from unsupported registers will return 0. Registers are not user configurable.

Table 2.1a. Local PCI Bridge Status Register.
Little Endian Bit|Big Endian Bit|Description|Supported by Local<br /> PCI Bridge Device
-|-|-|-
31|7|Detected Parity Error|Yes
30|6|Signaled System Error|Yes
29|5|Received Master Abort|Yes
28|4|Received Target Abort|Yes
27|3|Signaled Target Abort|No
26-25|2-1|DEVSEL Timing|No
24|0|Master Data Parity Error|Yes
23|15|Fast Back-to-Back Capable|No
22|14|Reserved|No
21|13|66 MHz Capable|No
20|12|Capabilties|No
19|11|Interrupt Status|Yes
18-16|10-8|Reserved|No

Table 2.1b. Local PCI Bridge Command Register.
Little Endian Bit|Big Endian Bit|Description|Default Value
-|-|-|-
15-11|23-19|Reserved|0
10|18|Interrupt Disable|0
9|17|Fast Back-to-Back Enable|0
8|16|_SERR Enable|1
7|31|Reserved|0
6|30|Parity Error Response|1
5|29|VGA Palette Snoop|0
4|28|Memory Write and Invalidate Enable|0
3|27|Special Cycles|0
2|26|Bus Master|0
1|25|Memory Space|1
0|24|I/O Space|0

## 2.2 AUTOCONFIG

PCI cards designed specifically with support for the AmigaPCI will be configured via the AUTOCONFIG process at startup. AUTOCONFIG capable PCI devices will be configured by the Local PCI Bridge in the 32-bit Zorro 3 address space. In order to complete the AUTOCONFIG process, all AUTOCONFIG capable PCI devices must inclue a ROM or psuedo-ROM to support the process. In order to be recognized as an AUTOCONFIG capable device, a PCI card must respond with with the value 0x68 at offset 0x14 in the ROM space (section 2.2.2.1).

> [!NOTE]
> A Type 0 configuration transaction is used to access a device on the current bus segment and a Type 1 configuration transaction is used to access a device that resides behind another bridge on the bus. For example, a daughter card plugged into a PCI slot can supply additional PCI slots via a bridge on the daughter card. A Type 0 configuration transaction is not forwarded across a bridge but is used to configure a bridge or other PCI devices that are connected to the PCI bus on which the Type 0 configuration transaction is generated*. 

*PCI-to-PCI Bridge Architecture Specification Revision 1.1. PCI Special Interest Group. Section 3.1. Overview of Hierarchical Configuration. pp. 19.

### 2.2.1 AUTOCONFIG Process

During configuration, specifications such as the device manufacturer, product number, device capabilities, etc, are read from the device. Each PCI device is capable of supporting up to six base address registers (BAR0 - BAR5, between 0x10 - 0x24 in the configuration register). The required address space for each of the six possible registers are determined and presented to Amiga OS for assigning of base addresses in the 32-bit Zorro 3 address space. This is done through the normal Zorro 3 AUTOCONFIG procedure. As an example, if BAR0 requests 512k of configuration space, this request will be passed to Amiga OS as a Zorro 3 device requiring 512k of AUTOCONFIG space. Amiga OS will then assign a base address to this request. This assigned base address will be programmed into BAR0 of the target PCI device. This process repeats for BAR1 - BAR5 of the same PCI device. This procedure is then repeated for each PCI device installed. Once complete, each PCI device may be accessed by the assigned base address, just as any other AUTOCONFIG device. PCI target devices configured by the AUTOCONFIG process may only access memory and configuration spaces. Use of the I/O space is not recommended for new PCI designs* and is not supported.

> [!NOTE]
> Amiga OS supports 8-bit Product IDs, so the Device ID field must consider this.
> Amiga OS supports 16-bit Vendor IDs, which is the same as PCI.

*PCI Local Bus Specification Revision 2.3. PCI Special Interest Group. Section 3.2.2. Addressing. pp. 27.

### 2.2.2 AUTOCONFIG ROM Vector

PCI devices may have onboard ROMs that enhance functionality, such as for auto booting. PCI ROMs may contain multiple images that support multiple architectures. During PCI configuration, the ROM address offset (AUTOCONFIG ROM Vector) is read from the PCI configuration header. This 16-bit value is then presented to the AUTOCONFIG process, which is an offset from the base address where the ROM will respond.

#### 2.2.2.1 PCI Data Structure

The first 64KB of ROM space is designated as the PCI Data Structure.* To determine the target architecture of the ROM image, the value Code Type must be set. For Amiga 68K ROM images, the Code Type at offset 0x14 must be **0x68**. All other values will be ignored. If this value is not set correctly, the device will not be configured with the AUTOCONFIG process.

> [!NOTE]
> **The Code Type value of 0x68 is an unofficial implementation of this register. By selecting a high value, it is expected this will never be officially assigned and should be safe far into the future.**

*PCI Local Bus Specification Revision 2.3. PCI Special Interest Group. Section 6.3.1.2. PCI Data Structure Format. pp. 212.

### 2.2.3 AUTOCONFIG PCI Device Register Access

PCI defines multiple address spaces that exist in parallel. PCI command encodings select a specific address space for the current cycle. PCI devices added by the AUTOCONFIG process may be accessed in memory or configuration spaces. Each device is accessed via the assigned base address with the command type determined by sampling **R_W**, and the **TT** and **TM** buses. For example, you can access the Configuration Type 0 space of an AUTOCONFIG PCI device by driving the base address on the **A** bus, setting the **TT** bus to 0x2 and the TM bus to 0x0. This can be accomplished via the MOVES command. The Local PCI Bridge will interpret this as a Configuration Type 0 command and set the **C/BE[3..0]** bits accordingly. Reference sections 3.2.5, 5.3.1, and 5.3.2 in the Motorola MC68040 manual for details on the MOVES instruction.

Table 2.2.3a. PCI Commands for AUTOCONFIG Devices.
R_W|TT1|TT0|TM2|TM1|TM0|PCI Command
-|-|-|-|-|-|-
1|0|x|x|x|x|Memory Space Read
0|0|x|x|x|x|Memory Space Write
1|1|0|0|0|0|Configuration Type 0 Space Read
0|1|0|0|0|0|Configuration Type 0 Space Write
x|1|0|0|0|1|Reserved by Motorola
x|1|0|0|1|0|Reserved by Motorola
1|1|0|0|1|1|Configuration Type 1 Space Read
0|1|0|0|1|1|Configuration Type 1 Space Write
x|1|0|1|0|0|Reserved
x|1|0|1|0|1|Reserved by Motorola
x|1|0|1|1|0|Reserved by Motorola
x|1|0|1|1|1|Reserved

### 2.2.3 PCI AUTOCONFIG Configuration

During the AUTOCONFIG process, up to 21 AUTOCONFIG capable PCI device slots may be addressed by the Local PCI Bridge, although the AmigaPCI has only five. During the configuration access, the Local PCI Bridge asserts **IDSEL** with one of 21 address bits, **A[31..11]**. Once the device has been configured, the device should only be accessed through its AUTOCONFIG assigned base address. Shown below is the list of possible AmigaPCI slot **IDSEL** addresses. This list maintains compatability with Prometheus* **IDSEL** addresses while allowing for expansion in the number of slots in new system designs.

Examples:
1) Applying address 0x0200 0000 will enable **IDSEL** of the card in slot 9.  
2) Applying address 0x8000 0000 will enable **IDSEL** of the card in slot 15.  

Table 2.2.3a. AUTOCONFIG Capable Slots.
PCI Slot|Address Bit|Offset|Prometheus Compatable
-|-|-|-
0|AD[16]|0x0001 0000|Yes*
1|AD[17]|0x0002 0000|Yes
2|AD[18]|0x0004 0000|Yes
3|AD[19]|0x0008 0000|Yes
4|AD[20]|0x0010 0000|No
5|AD[21]|0x0020 0000|No
6|AD[22]|0x0040 0000|No
7|AD[23]|0x0080 0000|No
8|AD[24]|0x0100 0000|No
9|AD[25]|0x0200 0000|No
10|AD[26]|0x0400 0000|No
11|AD[27]|0x0800 0000|No
12|AD[28]|0x1000 0000|No
13|AD[29]|0x2000 0000|No
14|AD[30]|0x4000 0000|No
15|AD[31]|0x8000 0000|No
16|AD[11]|0x0000 0800|No
17|AD[12]|0x0000 1000|No
18|AD[13]|0x0000 2000|No
19|AD[14]|0x0000 4000|No
20|AD[15]|0x0000 8000|No

*Prometheus daughter cards historically have 4 PCI Local Bus slots. It is assumed drivers designed for Prometheus will only search for devices at offsets 0x0001 0000 - 0x0008 0000.

## 2.3 Prometheus Enabled Device Configuration

The AmigaPCI aims to maintain a high level of compatabitly with Prometheus drivers. However, Prometheus implements non-standard PCI bridge registers. This means some drivers may need modification to work with the AmigaPCI. PCI devices not supporting AUTOCONFIG should be installed in a Prometheus configuration slot. Each slot designated as a Prometheus configuration slot may be accessed through the base address of the Local PCI Bridge, which is always configured by AUTOCONFIG at startup. Each slot on the PCI bus may be addressed individually by its offset value to read or write from that device's configuration register. To maintain compatability with existing Prometheus drivers, the system must support **IDSEL** on four slots driven by **A[19..16]**. These four slots also support AUTOCONFIG. Up to 17 additional slots may be added to support AUTOCONFIG only devices. See 2.2 AUTOCONFIG PCI Slots.

For a full understanding of intefacing Prometheus enabled devices, documentation of the Prometheus firmware should be reviewed.

Examples, assuming the PCI Local Bridge base address is 0x6000 0000:

1) Applying address 0x6001 0000 will enable **IDSEL** of the card in slot 0.  
2) Applying address 0x6008 0000 will enable **IDSEL** of the card in slot 3.  

Table 2.3a. Address Offset of PCI Slots For **IDSEL**.
PCI Slot|Address Bit|Offset From Base Address
-|-|-
0|AD[16]|0x0001 0000
1|AD[17]|0x0002 0000
2|AD[18]|0x0004 0000
3|AD[19]|0x0008 0000

# 3.0 Data Transfer Cycles and Bus Mastering

Direct bus* access is available to the CPU and PCI devices via bus mastering. When a device has mastered the bus, it has control of the entire AmigaPCI system and may directly access any valid address location. This is typically done for direct reading and writing of memory (DMA) or direct control of chipset or other functions. The AmigaPCI bus arbiter accepts bus requests from the CPU and each device on the PCI bus. Each slot on the PCI bus has a dedicated bus request signal. The bus arbiter implements a fairness protocol to prevent a single device from owning the bus for extended lengths of time. When there is no pending bus request, the CPU is given implicit ownership of the bus (**_BG** is asserted with **_BB** held in a high impedence state) until it the CPU begins a bus cycle or a bus request from a PCI device is granted. 

*In this discussion, "bus" is a term for the data, address, and AD buses, collectively, of the Amiga.

## 3.1 CPU as a Bus Driver

Unlike previous Motorola MC68000 series processors, the Motorola MC68040 does not preferentially own the bus. It is considered for bus access with all other bus mastering devices on the system. Thus, bus arbitration includes consideration for the CPU when assigning bus ownership. When it is ready to take ownership of the system bus the CPU will assert **_BR** (bus request) to indicate its need to own the system bus. When there are no current bus cycles in progress, the arbiter will assert **_BG** (bus grant) in response so that the CPU may begin its bus activities. Once **_BG** is asserted by the arbiter, the CPU will assert **_BB** (bus busy) to indicate ownership of the bus. **_BG** is asserted until the CPU bus access is complete, indicated by negation of **_BR**. While posessing explicit ownership of the bus, the CPU may start a bus cycle at any time by asserting **_BB**. The CPU is granted implicit ownership of the bus when no other device is requesting, or has been granted, bus ownership. During implicit ownership of the bus, the CPU leaves the bus in an undefined state, while **_BG** is asserted, **_BR** is negated, and **_BB** is tri-state.

### 3.1.1 CPU Driven Data Transfer Cycle

CPU access to PCI target devices supports burst (MOVE16) and non-burst (normal) cycles in read and write modes. The PCI and CPU busses operate at different clock rates. This raises concerns about metastability and honoring setup and hold times for data transfers. In order to account for these concerns, the AmigaPCI Local Bridge implements a FIFO approach. FIFO allows clock domain crossing supporting the quickest release of the CPU, shortening cycle times.

When a data transfer cycle is initiated by the CPU, the Local PCI Bridge broadcasts the address and related bus command to the PCI bus. If a target device responds by asserting **_DEVSEL** within two PCI clock cycles, the Local PCI Bridge completes the transfer. If no device asserts **_DEVSEL** by the second falling edge of the PCI clock, the Local PCI Bridge returns to an idle state. See Master Terminated, Section 8.2.

### 3.1.2 Normal Mode Cycles

A normal mode transfer is capable of moving byte, word, or long word data. The data size to be transfered is determined from **A[1..0]** and the **SIZ0** and **SIZ1** CPU signals. That information is used to drive the correct byte enables on **C/BE[3..0]** during the data transfer.

### 3.1.3 Burst Mode Cycles

A burst mode is defined as a line transfer initiated by the CPU with the MOVE16 instruction*. This results in the burst transfer of four long words to or from the target device. Each long word being aligned to a 16-byte memory boundary. During CPU initiated burst transfers, all four bytes are enabled. The PCI target device must internally increment **A3** and **A2** of the supplied address for each transfer, causing the address to wrap around at the end of the block. This is consistent with the Cacheline Wrap Mode burst order defined in the PCI specifications**.

*Motorola MC68040 User Manual. Motorola. Sections 7.4.2 Line Read Transfer and 7.4.4 Line Write Transfers.
**PCI Local Bus Specification Revision 2.3. PCI Special Interest Group. Table 3-2. Burst Ordering Encoding. pp. 29.

## 3.2 PCI Device as a Bus Driver (DMA)

A DMA cycle is defined as a PCI device taking control of the system bus of the AmigaPCI during normal bus arbritration. The PCI device owning the bus may access any valid address space of the AmigaPCI, including other devices on the PCI bus. When accessing memory spaces of the AmigaPCI, only memory space PCI commands are allowed.

### 3.2.1 PCI Driven Data Transfer Cycle (DMA)

When a PCI device wants to take ownership of the system bus, it will assert **_REQx**, where x is the slot designation of the device. Once the arbiter has granted the bus to the requesting PCI device, the arbiter will assert **_GNTx** and **_BB** to indicate a bus operation is in progress, allowing the requesting PCI device to take ownership of the bus and begin the data transfer cycle. The PCI device should never start a DMA cycle until it has been granted exclusive bus access by assertion of the relevant **_GNTx** signal. **_BB** will remain asserted while either the PCI bus or CPU bus remains active in the current cycle.

During DMA cycles, the cycle is directed by the initiating PCI device. The Local PCI Bridge is responsible for driving MC68040 compatable signals on the CPU bus to support the current cycle. These signals are **_TS**, **_TIP**, **R_W**, **TT0**, **TT1**, **SIZ0**, **SIZ1**, **A[31..0]**, and **D[0..31]** (write cycle only). When not actively driving a DMA cycle on the CPU bus, these Local Bridge holds these signals in a high impedence state. The Local PCI Bridge must respond to the assertion of **_TA** in order to recognize when data is placed on **D[0..31]** for read cycles, or when data has been latched by the target device for write cycles. Unless actively driving a DMA cycle against onboard AmigaPCI resources, **AD[31..0]**, **_TRDY**, **_DEVSEL** must be held in a high impedence state by the Local PCI Bridge during DMA cycles.

#### 3.2.1.1 Transfer Type

The Local PCI Bridge will assert **TT0** and **TT1**, as required, in response to a normal or burst transfer request from the PCI initiating device. The assertion of transfer type (**TT0** and **TT1**) is determined by whether **_FRAME** is held asserted after the address phase of the current cycle. If **_FRAME** is negated on the first rising PCI clock edge after the address phase, this is a normal cycle. If **_FRAME** is held asserted on the first rising PCI clock edge after the address phase, this is a burst cycle. This means the Local PCI Bridge cannot set **TT0** and **TT1** until the first falling BCLK edge after the first rising PCLK edge after the cycle address phase.

#### 3.2.1.2 Bus Synchronization

It must be considered that the PCI bus clock and the MC68040 bus clocks are asynchronous. If not handled correctly, this can lead to a condition where the devices become out of sync. This will result in data transfer errors. While PCI initiator devices may, or may not, insert wait states, we must consider this possiblity as wait states are defined in the PCI specification for all cycle types. Synchronozation of the bus clocks is acheived by the PCI Local Bridge implementing a FIFO approach. Data is latched into a register in one clock domain and passed out to the other clock domain at the appropriate timings.

## 3.3 Cycle Termination

The PCI cycle can end in several ways and may be terminated by the Local PCI Bridge or target device.

### 3.3.1 Master Terminated - Completion

This condition is asserted when the master device has completed the intended transaction without error. This terminiation condition is signaled by negating **_FRAME** while **_IRDY** is asserted.

### 3.3.2 Master Terminated - Abort

This condition exists when no target device responds to the address phase of a PCI cycle. Normally, a PCI Target Device will claim the cycle by asserting the **_DEVSEL** signal in response to the address phase of the cycle. If no device claims the cycle, it is assumed to be the absence of a target device with a matching base address, rather than a bus error. The Local PCI Bridge will return to an idle state. No signals are asserted in response to this condition.

### 3.3.3 Target Terminated - Retry

This condition is signaled when the target device asserts **_STOP** after claiming the cycle, by asserting **_DEVSEL**, before data has been transfered. When the target device asserts the retry condition, the Local PCI Bridge will assert **_TA** and **_TEA** together, which signals the CPU to immediately abort and retry the cycle.

### 3.3.4 Target Terminated - Disconnect

This condition is signaled when the target device asserts **_STOP** while **_TRDY** is asserted. The Disconnect condition is different from the Retry condition in that Disconnect is asserted after some data has already been transfered, but the target device is unable to continue transferring the requested data. When this condition exists, the Local PCI Bridge will assert **_TEA**. This indicates to the CPU that an error condition exists and the cycle cannot continue. This condition can only exist for burst cycles.

### 3.3.5 Target Terminated - Abort

This condition can exist any time after a target device has asserted **_DEVSEL** and is signaled when the target device asserts **_STOP** and negates **_DEVSEL** simultaneously. This is considered an abnormal termination in that the target device will never be able to supply to requested data. When this condition exists, the Local PCI Bridge will assert **_TEA**. This indicates to the CPU that an error condition exists and the cycle cannot continue. This condition may occur for both burst and normal cycles. This condition is treated the same as the Target Terminated - Disconnect condition by the CPU (Section X.X.X). See Figure X.X.X for example timing.

### 3.3.6 Master Terminated Cycle - Timeout

**Add something here**. This is timeout during DMA situations.

## 3.4 Parity

Data transfer cycle errors are detected using an even parity system. Except for video and HID devices, all PCI devices are required to support parity*. Even parity is generated by the initiating device and **PAR** is valid one clock after the associated address or data block. The target device determines even parity on the data received and compares the calculated value to **PAR**. Even parity is set when the number of set bits on **AD[31..0]**, **C/BE[3..0]**, and **PAR** is an even number. Parity error conditions are expected to be reported through the device driver whenever possible**. The reporting chain of target to bus master to driver to operating system enables recovery options at every level. The information below specifically explains how the Local PCI Bridge of the AmigaPCI handles parity errors.

*PCI Local Bus Specification Revision 2.3. PCI Special Interest Group. Section 3.7.2. Parity Checking. pp. 95.  
**PCI Local Bus Specification Revision 2.3. PCI Special Interest Group. Section 3.7.4. Error Reporting. pp. 95. 

### 3.4.1 Address Parity Errors

An address parity error occurs when a parity mismatch is detected during the address phase of the PCI cycle and is generally considered a fatal condition.  When a target device detects an address parity error, it will set the Detected Parity Error bit (Status register, bit 15). If the Parity Error Response bit is set (Command Register, bit 6), the target device will assert **_PERR**. If the _SERR Enable bit is set (Command Register, bit 8), the System Error Bit is set (Command Register, bit 8). 

When a parity mismatch occurs during the address phase, one of three things can happen:

1) A device, possibly an unintended target, claims the transaction and proceeds as normal.
2) A device, possibly an unintended target, claims the transaction and terminates with a Target-Abort.
3) No target device claims the transaction and the cycle will time out with a Master-Abort.

The Local PCI Bridge considers two back-to-back address parity errors to be a fatal condition. In the event of an address parity error during a CPU driven data transfer cycle, the Local PCI Bridge will request the MC68040 retry the cycle one time. In the case of a second address parity error, if the _SERR Enable bit is set (Command Register, bit 8), the Local PCI Bridge will set the Signaled System Error bit (Status Register, bit 14). This is a signal to drivers that a fatal condition exists within the PCI bus and efforts should be made to save any needed data, cease accessing the PCI bus, and warn the user. Once in a fatal condition, the Local PCI Bridge will return 0xFFFF FFFF for all reads and writes will have no effect. Once set, the Signaled System Error bit will remain set until a system reset.

**Note:** During CPU driven cycles, the PCI device is the target device. During DMA cycles, the Local PCI Bridge or other PCI device is the target device.

### 3.4.2 Data Parity Errors

A data parity error occurs when there is a parity mismatch during the data phase of the cycle. Data parity is calculated on all data blocks except during special cycles. When the target device detects a data parity error, it will set the Detected Parity Error bit (Status register, bit 15). If the Parity Error Response bit is set (Command Register, bit 6), it will assert **_PERR**. In response to the assertion of **_PERR**, the Local PCI Bridge will assert **_INT2** and set the Interrupt Status bit (Status Register, Bit 3), indicating the interrupt is generated from a device on the PCI bus. PCI drivers are expected to respond to this interrupt and poll their device's Parity Error Bit. The driver should clear the interrupt from the device and retry the transfer cycle. If an excessive number of parity errors occur, the driver should attempt to gracefully disconnect (cease using) the device with a user warning. All efforts should be made to save the user session. Failure to do so will likely result in a system crash and possibly lost data.

**Note:** During CPU driven cycles, the PCI device is the target device. During DMA cycles, the Local PCI Bridge or other PCI device is the target device.

**END**

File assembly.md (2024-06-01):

## Tables

### Table 1. Legacy Parts Required
Common Name|Designation/Part Number|Postion|Package|Notes
-|-|-|-|-
Fatter Agnus|See Table 2|U202|PLCC-84|
Paula|MOS 8364|U500|DIP-48|
Denise|MOS 8362 or CSG 8373|U300|DIP-48|[Deniser](https://github.com/endofexclusive/deniser)
CIA|MOS 8520A, 8520A-1, 8520R2, or 8520PD|U203 and U204|DIP-40|These are all interchangeable
Kickstart|Burn your own A3000 27C4096|U210 (LOW), U211 (HIGH)|DIP-40|
Video Hybrid|Commodore 390229-0x|HY300|SIP-22|[Video Hybrid](https://github.com/SukkoPera/OpenAmigaVideoHybrid)

*Commodore IC's may be marked "MOS" or "CSG", or possibly neither in the case of contract runs. These are interchangeable by part number.

### Table 2. Agnus Parts Supported

Agnus|Commodore Part Number|Status
-|-|-
8372A|ALL|Tested and working
8375|390544-01|Tested and working
8375|390544-02|Tested and working
8375|318069-10|Tested and working
8375|318069-11|Tested and working
8375|390554-01|Unknown
8375|390554-02|Unknown
8375|318069-12|Unknown
8375|318069-13|Unknown

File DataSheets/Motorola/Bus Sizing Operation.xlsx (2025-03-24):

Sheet: Read
 | 68040 |  |  |  | AMIGA
Desc | UU | UM | LM | LL | UU | UM | LM | LL
Address | 00 | 01 | 10 | 11 | 00 | 01 | 10 | 11
Byte | 3 | 2 | 1 | 0 | 3 | 2 | 1 | 0
Any transfer from long word port
 |  |  |  |  |  |  |  |  | FLIP | A[1] | SIZ | PORTSIZE | A[1:0]
Transfer 0 | UU | UM | LM | LL | UU | UM | LM | LL | 0 | 0 | 00,11 | 0 | Passthrough
Long word transfer from word port
Transfer 0 | UU_LATCH | UM_LATCH | x | x | UU | UM | x | x | 0 | 0 | 00,11 | 1 | Drive
Transfer 1 | x | x | UU | UM | UU | UM | x | x | 1 | 1 | 00,11 | 1 | Drive
Upper word transfer from word port
Transfer 0 | UU | UM | x | x | UU | UM | x | x | 0 | 0 | 01,10 | 1 | Passthrough
Lower word transfer from word port
Transfer 0 | x | x | UU | UM | UU | UM | x | x | 1 | 1 | 01,10 | 1 | Passthrough

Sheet: Write
 | 68040 |  |  |  | AMIGA
Desc | UU | UM | LM | LL | UU | UM | LM | LL
Address | 00 | 01 | 10 | 11 | 00 | 01 | 10 | 11
Byte | 3 | 2 | 1 | 0 | 3 | 2 | 1 | 0
Any transfer to long word port
 |  |  |  |  |  |  |  |  | FLIP | A[1] | SIZ | PORTSIZE | A[1:0]
Transfer 0 | UU | UM | LM | LL | UU | UM | LM | LL | 0 | 0 | 00,11 | 0 | Passthrough
Long word transfer to word port
Transfer 0 | UU | UM | LM | LL | UU | UM | x | x | 0 | 0 | 00,11 | 1 | Drive
Transfer 1 | UU | UM | LM | LL | LM | LL | x | x | 1 | 1 | 00,11 | 1 | Drive
Upper word transfer to word port
Transfer 0 | UU | UM | x | x | UU | UM | x | x | 0 | 0 | 01,10 | 1 | Passthrough
Lower word transfer to word port
Transfer 0 | x | x | LM | LL | LM | LL | x | x | 1 | 1 | 01,10 | 1 | Passthrough

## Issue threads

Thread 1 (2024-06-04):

Wow!

mheyer32, 2024-06-04:
Let me just say: Awesome endeavor!

DvdBoon, 2024-06-04:
I second that. This has come a long way since the start of the year. Also, PCI driver development has spiked the last month :-)

jasonsbeer, 2024-06-04:
Thanks! I appreciate the positive vibes.

mheyer32, 2024-06-05:
This board is exactly what I was hoping for. It represents something that Commodore could have done.... an Amiga with PCI and native 040/060 bus. I'm looking forward seeing it succeed and I'm very curious about the benchmarks after throwing the old 030 cruft over board.

DisasterIncarnate, 2024-06-06:
ambitious indeed, hope you refine and improve, maybe others might do something similar, love seeing modern projects like this.

CodehunterWorks, 2024-11-05:
I happened to see this project in a german discussion about the OpenPCI project. At first: I agree totally with the TO... WOW! It is a very cool idea.

I have some thoughts about your project:

1. Looks like an Realization of this old A5000 Block Diagram from C= [posted by Historical Society some Weeks ago](https://x.com/commodoreihs/status/1834384021570060479) except how the CPU Module is attached. Haynie had planned to plug it into an PCI slot I think. But your Way is better.
2. Its an really nice Idea to have Jumpers to switch between Amiga and PC Floppy Drives!
3. Why do you have designed this Board with an PCI 2.3 Bus but placed the Slots in PCI 2.1 Style? Means: 5 Volts instead of 3.3 Volts and the Notch at the wrong Side? I think most PCI Cards were produced for 3.3 Volts and only few for both with two Notches (for e.g. SoundBlaster PCI Cards).
4. Although it has nothing directly to do with OpenPCI: Would it benefit from a mutual exchange?
5. I suggest to add an MicroSD slot aside the ROM section to load the Kick from SD instead of an 27C4096 (most Hobbyists does not have an EPROM Burner). This would be a more modern Way to deal with ROMs and is more flexible.
6. How fast can the IDE port work? The native IDE Port in the A1200s was not really good...
7. What do you think about integrated Scandoublers/Flickerfixers switchable also by Jumpers wired to the DB15 Connector?
8. It would be pretty awesome if there was an PiStorm that could be plugged directly into the CPU slot - without any "sandwich" adapter stack (I dont like such layered Cakes because of risk of wobbly Contacts and decrease of Signal Quality). PiStorm is the fastest (and inexpensive IMHO) Accelerator available this days and Michal is also an nice and friendly Hardware Researcher like you. I think an Combination of these two Projects has the Potential to an worthy Successor of the A4000.

At last: I really like your Ideas, even if my Thoughts above would not happen :-)

Closed 2025-07-15.

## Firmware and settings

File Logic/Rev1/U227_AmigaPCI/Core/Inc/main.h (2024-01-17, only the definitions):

#define _FORWARD_Pin GPIO_PIN_0
#define _FORWARD_GPIO_Port GPIOC
#define _BACK_Pin GPIO_PIN_1
#define _BACK_GPIO_Port GPIOC
#define _LEFT_Pin GPIO_PIN_2
#define _LEFT_GPIO_Port GPIOC
#define _RIGHT_Pin GPIO_PIN_3
#define _RIGHT_GPIO_Port GPIOC
#define POTX_Pin GPIO_PIN_4
#define POTX_GPIO_Port GPIOA
#define _FIRE_Pin GPIO_PIN_5
#define _FIRE_GPIO_Port GPIOA
#define D0_Pin GPIO_PIN_6
#define D0_GPIO_Port GPIOA
#define D1_Pin GPIO_PIN_7
#define D1_GPIO_Port GPIOA
#define D2_Pin GPIO_PIN_4
#define D2_GPIO_Port GPIOC
#define D3_Pin GPIO_PIN_5
#define D3_GPIO_Port GPIOC
#define _RTCWR_Pin GPIO_PIN_0
#define _RTCWR_GPIO_Port GPIOB
#define _RTCRD_Pin GPIO_PIN_1
#define _RTCRD_GPIO_Port GPIOB
#define A2_Pin GPIO_PIN_2
#define A2_GPIO_Port GPIOB
#define A3_Pin GPIO_PIN_10
#define A3_GPIO_Port GPIOB
#define A4_Pin GPIO_PIN_11
#define A4_GPIO_Port GPIOB
#define A5_Pin GPIO_PIN_12
#define A5_GPIO_Port GPIOB
#define POTY_Pin GPIO_PIN_6
#define POTY_GPIO_Port GPIOC
#define _HIDEN_Pin GPIO_PIN_7
#define _HIDEN_GPIO_Port GPIOC
#define KBDATA_Pin GPIO_PIN_8
#define KBDATA_GPIO_Port GPIOC
#define _KBCLK_Pin GPIO_PIN_9
#define _KBCLK_GPIO_Port GPIOC
#define _KBRST_Pin GPIO_PIN_10
#define _KBRST_GPIO_Port GPIOC

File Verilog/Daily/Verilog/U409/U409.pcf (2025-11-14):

#CLOCKS
set_io RESETn     62
#set_io CLK6       52
set_io TICK60     63
set_io TICK50     64
set_io XCLK       93
set_io CLK28_IN   94
set_io AGNUS_CLK  97
set_io CLK_CIA   122
set_io CLK40_IN     129
set_io XCLK_ENn  102

#CPU DATA BUS
#set_io D[0] 38 #D24
#set_io D[1] 39 #D25
#set_io D[2] 41 #D26
#set_io D[3] 42 #D27
#set_io D[4] 43 #D28
#set_io D[5] 44 #D29
#set_io D[6] 45 #D30
#set_io D[7] 47 #D31

#CPU ADDRESS BUS
set_io A[1]  144
set_io A[2]  143
set_io A[3]    1 
set_io A[4]   18
set_io A[5]   19
set_io A[6]   20
set_io A[7]   21
set_io A[8]   22
set_io A[9]   23
set_io A[10]  24
set_io A[11]  25
set_io A[12]  26
set_io A[13]  28
set_io A[14]  29
set_io A[15]  31
set_io A[16]  32
set_io A[17]  33
set_io A[18]  34
set_io A[19]  37
set_io A[20]  17
set_io A[21]  15 
set_io A[22]   3
set_io A[23]  16
set_io A[24]   8
set_io A[25]  12
set_io A[26]   4
set_io A[27]  11
set_io A[28]   2
set_io A[29]   7
set_io A[30]   9
set_io A[31]  10

#DATA TRANSFER SIGNALS
set_io TCIn         117
set_io TBIn         118
set_io PORTSIZE     135
set_io TACKn        119
set_io TSn          134
set_io TT[0]        138
set_io TT[1]        139
set_io ROM_DELAY[1] 107 -pullup yes
set_io ROM_DELAY[0] 106 -pullup yes
set_io RnW          142
#set_io TM[0]        136
#set_io TM[1]        137
#set_io TM[2]        141

#ADDRESS SPACE SIGNALS
set_io OVL        83
set_io RAMSPACEn  48
set_io CIACS0n    80
set_io CIACS1n    81
set_io REGSPACEn 120
set_io BUF_ENn    121
set_io ROM_ENn    124
set_io RTC_ENn    82
set_io CPUCONFn  130

#PCI BRIDGE
set_io CONFIGENn 56
#set_io BREG_ENn  91
set_io BRIDGE_ENn  55 -pullup yes
#set_io PCIAT[1]  73
#set_io PCIAT[0]  74

#ATA
set_io ATA_ENn   90
set_io PCS0      75
set_io PCS1      76
set_io SCS0      78
set_io SCS1      79
set_io PPIO      87
set_io SPIO      88
set_io AUTOBOOT 110 -pullup yes
set_io PPIO_J   112 -pullup yes
set_io SPIO_J   113 -pullup yes

#FLASH
#set_io FLASH_RDY    101
set_io FLASH_DISJn   114 -pullup yes
set_io FLASH_ENn      95
set_io FLASH_WPn      99
set_io FLASH_READn    96
set_io FLASH_WRITEn   60
set_io FLASH_RSTn     61
set_io FLASH_BANK[1]  84
set_io FLASH_BANK[0]  85

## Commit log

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2023-05-22 RESET Logic
    [bcontroller.kicad_sch, chip_memory.kicad_sch, floppy.kicad_sch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]
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2024-03-09 U409 Fixes and Test Bench 09-MAR-2024
    [U227_AmigaPCI.ioc]
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2024-05-09 Fix female DIN 41612 Female Footprint 08-MAY-2024
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2024-05-27 Main Board Rev 3.0 Rules Check and Fixes 26-MAY-2024
    [bcontroller.kicad_sch, clocks.kicad_sch, pci-bridge.kicad_sch]
2024-05-28 Main Board Logic Fixes 27-MAY-2024
    [1-5145167-2.STEP, 5530843-3.step, 5535098-5.stp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]
2024-05-29 Rev 3.0 Final Design Lock 28-MAY-2024
    Final Rev 3.0 main board and final Rev 1.0 68040 local bus card.
    [5650910-5.stp, Agnus-Multi.kicad_sch, AmigaPCI Mainboard.kicad_sch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]
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2024-06-09 Fix CIA Chip Select Timing 09-JUN-2024
    CIA chip select timing fixed to prevent asserting during the high phase of the CIA clock.
    [U409.pcf]
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2024-06-28 Chip RAM DMA Byte Enable Fix 27-JUN-2024
    Byte enables for DMA cycles were reversed.
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2024-07-03 Changes to U409 and U712 Verilog. See comments. 02-JUL-2024
    U409:
    Removed _TCI. Transfer caching only applies to line burst transfers, so this is not needed here.
    Removed _TBI. U409 only handles 16-bit data transfers, so bursting is not an option anyhow.
    Removed the "pull high" _TA process. Not needed as _TA is pulled high before leaving the address space.
    Fixed short cycle assertion of _TA.
    U712:
    Moved assertion of CMA bus to clocked process.
    Removed the "pull high" _TA process. Not needed as _TA is pulled high before leaving the address space.
    [U409.pcf]
2024-07-03 Schematic Changes for Rev 4.0 03-JUL-2024
    Remove _TIP, replace with GND at CN200.
    Add _TS to U712.
    Remove _TCI and _TBI from U409.
    [Agnus-Multi.kicad_sch, AmigaPCI Mainboard.kicad_sch, IDE.kicad_sch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]
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2024-07-03 Folder cleanup, address _TIP on CLBC. 03-JUL-2024
    Disconnected _TIP from A1 of DIN connector.
    Added 2.7k pullup to _TIP.
    Changed pin A1 of DIN connector to GND.
    [1-5145167-2.STEP, 5145154-4.step, 5530843-3.step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]
2024-07-09 CPU Local Bus Card Rev 3.0 Schematic 08-JUL-2024
    Start work on dynamic bus sizing logic.
    [5145154-4.step, 5650910-5.stp, AmigaPCI 68040.kicad_sch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]
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2024-07-10 Schematic Changes to Clocks 09-JUL-2024
    Make changes to support clock generation on CPU local bus card.
    [Agnus-Multi.kicad_sch, AmigaPCI Mainboard.kicad_sch, IDE.kicad_sch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]
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2024-07-16 CPU Local Bus Card routing. 15-JUL-2024
    Board is now 6 layers to provide adequate +5V to the 68040.
    [AmigaPCI 68040.kicad_sch, CPU.kicad_sch, CardConnector.kicad_sch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]
2024-07-17 AmigaPCI Rev 4.0 Schematic Updates 17-JUL-2024
    Changed reset circuit, added _DSACKx, Dropped _LOCKE from Local Bus Port, added CPU Reset In to Local Bus Port.
    [Agnus-Multi.kicad_sch, AmigaPCI Mainboard.kicad_sch, CPU.kicad_sch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]
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2024-07-20 CPU Local Bus Card schematics and routing, misc changes to readme's.
    This should be project lock for the Rev 3.0 CPU Local Bus Card.
    [AmigaPCI 68040.kicad_sch, CPU.kicad_sch, CardConnector.kicad_sch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]
2024-07-21 Finalize 68040 Local Bus Card.
    Added jumper to hold _BG for testing.
    Added 22ohm series resistor to R_W.
    [AmigaPCI 68040.kicad_sch, CPU.kicad_sch, CardConnector.kicad_sch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]
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2024-08-01 AmigaPCI - swap U810 & U811 with SN74LVC16T245DLR
    Drive Agnus DBR bus with TTL levels.
    [Agnus-Multi.kicad_sch, AmigaPCI Mainboard.kicad_sch, IDE.kicad_sch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]
2024-10-23 Move Rev 4.0 APCI board to current rev.
    Moved Rev 3.0 to archive.
    Upload AmigaPCI Rev 4.0 gerbers.
    [1-5145167-2.STEP, 5145154-4.step, 5530843-3.step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]
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2024-10-26 Move Rev 4.0 Local Bus Card to current revision status.
    Rev 3.0 moved to archive.
    [5145154-4.step, 5650910-5.stp, AmigaPCI 68040.kicad_sch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]
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2024-12-06 Additions and fixes to FPGA verilog.
    U712 - Fixed issues with DRD bus contention.
    U111 - Added long word <-> word data transfers.
    [U111_TOP_pin_table.CSV, U111_TOP_sbt.sdf, U111_TOP_sbt_vital.sdf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]
2024-12-14 U111 - Fixed byte transfer issue.
    Fixed bus sizing issue with byte transfers to long word ports.
    [U111_TOP_pin_table.CSV, U111_TOP_sbt.sdf, U111_TOP_sbt_vital.sdf]
2024-12-15 Chip RAM cycles now working.
    Delayed assertion of _TACK one clock to let the signals settle before latching.
    [U712_TOP_pin_table.CSV, U712_TOP_sbt.sdf, U712_TOP_sbt_vital.sdf]
2024-12-17 Verilog Updates (See Description)
    U409: Removed lots of commented code.
    U712: Move assertion of _TACK into state 5 for register cycles.
    U111: Enable caching for all transfers.
    [U111_TOP_pin_table.CSV, U111_TOP_sbt.sdf, U111_TOP_sbt_vital.sdf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]
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2024-12-19 Enable 2MB chip RAM CPU cycles.
    Logic is there and tested, but won't be fully implemented until Rev 4.1 hardware.
    [U712_TOP_pin_table.CSV, U712_TOP_sbt.sdf, U712_TOP_sbt_vital.sdf]
2024-12-19 Logic Updates - See Description.
    U111 - Transfer state machine was not initiating transfer of second word of a long word transfer to a word port. Fixed.
    U712 - Register state machine was not starting in response to the second word of a long word transfer. Fixed.
    [U111_TOP_pin_table.CSV, U111_TOP_sbt.sdf, U111_TOP_sbt_vital.sdf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]
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2024-12-23 Verilog updates. See description.
    U409: Deactivate unresponsive ack for cycles in the Agnus spaces.
    U712: Fixed glitch with refresh cycle trying to start during data transfer cycle.
    [U409_TOP_pin_table.CSV, U409_TOP_sbt.sdf, U409_TOP_sbt_vital.sdf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]
2024-12-24 U712: Fixed R/W glitch in DMA cycles.
    [U712_TOP_pin_table.CSV, U712_TOP_sbt.sdf, U712_TOP_sbt_vital.sdf]
2024-12-25 U712: Add synchronizer to SDRAM refresh process.
    The system would occasionally crash during chip RAM testing. Fixed.
    [U712_TOP_pin_table.CSV, U712_TOP_sbt.sdf, U712_TOP_sbt_vital.sdf]
2024-12-26 U712: Rework of SDRAM state machine.
    Still chasing down edge cases/crashes.
    [U712_TOP_pin_table.CSV, U712_TOP_sbt.sdf, U712_TOP_sbt_vital.sdf]
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2025-01-05 Update U712_BYTE_ENABLE.v
    Fix DMA byte enables for lower word.
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2025-01-09 U712 Changes. See description.
    1) Finished up CPU chip RAM and DMA cycles. Appears to be stable.
    2) Lots of Verilog cleanup.
    [U712_TOP_pin_table.CSV, U712_TOP_sbt.sdf, U712_TOP_sbt_vital.sdf]
2025-01-09 U712: Ignore Agnus DRAM refresh cycles.
    We use the Agnus refresh time for CPU RAM cycles.
    [U712_TOP_pin_table.CSV, U712_TOP_sbt.sdf, U712_TOP_sbt_vital.sdf]
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2025-01-25 U712: Stabilized register cycles.
    Addressed some irregularities in the register cycles due to marginal timing.
    [U712_TOP_pin_table.CSV, U712_TOP_sbt.sdf, U712_TOP_sbt_vital.sdf]
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2025-01-26 U409 - Fixed ROM TACK delay counter.
    [U409_TOP_pin_table.CSV, U409_TOP_sbt.sdf, U409_TOP_sbt_vital.sdf]
2025-02-01 Update LBC logic for Rev 4.1 board.
    Build files for U400 and new folders.
    [U111_TOP_pin_table.CSV, U111_TOP_sbt.sdf, U111_TOP_sbt_vital.sdf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]
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2025-02-05 Fix transfer burst inhibit signal in U111.
    [U111_TOP_pin_table.CSV, U111_TOP_sbt.sdf, U111_TOP_sbt_vital.sdf]
2025-02-08 Rebuilt all verilog to enable floating of unused pins.
    You must check "Set all unused IO no pullup" Under Tool -> Tool Option -> Bitmap. Otherwise, all unused gates are driven high.
    [U109_TOP_pin_table.CSV, U109_TOP_sbt.sdf, U109_TOP_sbt_vital.sdf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]
2025-02-09 U409: Cleaned up ROM cycle.
    When changing addresses, the 27C4096 ROM drives all the data bits high. This makes noisy data transitions between addresses when output enable is held asserted for back-to-back ROM cycles. This was c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
    [U409_TOP_pin_table.CSV, U409_TOP_sbt.sdf, U409_TOP_sbt_vital.sdf]
2025-02-19 U712: Enable latching of DRD bus during DMA read cycles.
    This change saves a few clock cycles during chipset DMA reads.
    [U712_TOP_pin_table.CSV, U712_TOP_sbt.sdf, U712_TOP_sbt_vital.sdf]
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2025-03-10 Local Bus Card : Enable onboard fast RAM.
    Fast RAM with burst support is added. Burst mode is not yet tested. Non-burst has been tested with Diagrom. Coprocessor expansion address space $0800 0000 to $0FFF FFFF is implemented.
    [U111_TOP_pin_table.CSV, U111_TOP_sbt.sdf, U111_TOP_sbt_vital.sdf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]
2025-03-11 LBC U400 : Added pullup to _LBEN to clean up some early shenanigans.
    [U400_TOP_pin_table.CSV, U400_TOP_sbt.sdf, U400_TOP_sbt_vital.sdf]
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2025-03-16 U712 : Added latching buffers to register write cycle.
    This will free up the CPU sooner on write cycles. Should save about 200ns per register write cycle.
    [U712_TOP_pin_table.CSV, U712_TOP_sbt.sdf, U712_TOP_sbt_vital.sdf]
2025-03-17 U712 : Fixed Paula DMA crash.
    Was an issue with the direction and/or enable signal for U810. Also includes some code cleanup.
    [U712_TOP_pin_table.CSV, U712_TOP_sbt.sdf, U712_TOP_sbt_vital.sdf]
2025-03-21 U409 Fixes - See Description
    Fixed back-to-back CIA cycles.
    Added data and code space address decode conditions.
    [U409_TOP_pin_table.CSV, U409_TOP_sbt.sdf, U409_TOP_sbt_vital.sdf]
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2025-03-29 U712 : Rework register state machine.
    Timings were bad. These are much better.
    [U712_TOP_pin_table.CSV, U712_TOP_sbt.sdf, U712_TOP_sbt_vital.sdf]
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2025-03-30 U712: Fix register state machine start reset.
    [U712_TOP_pin_table.CSV, U712_TOP_sbt.sdf, U712_TOP_sbt_vital.sdf]
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2025-04-14 U409 : Fix Ranger space decode.
    [U409_TOP_pin_table.CSV, U409_TOP_sbt.sdf, U409_TOP_sbt_vital.sdf]
2025-04-19 U111: New bus sizing state machine.
    This new state machine handles all cycles. This allows us to handle additional cycle termination types that have not yet been implemented.
    [U111_TOP_pin_table.CSV, U111_TOP_sbt.sdf, U111_TOP_sbt_vital.sdf]
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2025-05-07 U712: Update DMA and chip ram timings.
    1) Start DMA cycles earlier by implementing a 8Mx32 SDRAM, which provides more headroom. We were barely getting data on the chipset bus in time with the original 2Mx32 SDRAM.
    2) Open up time during DMA for CPU chip ram cycles, which speeds up the chip ram a great deal.
    [U712_TOP_pin_table.CSV, U712_TOP_sbt.sdf, U712_TOP_sbt_vital.sdf]
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2025-05-09 U712: Stabilize DMA cycles.
    [U712_TOP_pin_table.CSV, U712_TOP_sbt.sdf, U712_TOP_sbt_vital.sdf]
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2025-05-24 APCI Rev 6.0 work.
    Replace TS213 with AZ75232 serial driver to fix audio filter issue.
    [audio.kicad_sch, floppy.kicad_sch, hid.kicad_sch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]
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2025-05-31 U111: Fixed burst count value.
    [U111_TOP_pin_table.CSV, U111_TOP_sbt.sdf, U111_TOP_sbt_vital.sdf]
2025-06-01 U111: Fixed bus contention during on-board RAM cycle.
    [U111_TOP_pin_table.CSV, U111_TOP_sbt.sdf, U111_TOP_sbt_vital.sdf]
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2025-06-07 U409: Fixed ATA ROM disable.
    [U409_TOP_pin_table.CSV, U409_TOP_sbt.sdf, U409_TOP_sbt_vital.sdf]
2025-06-13 U111: Fixed bus sizing SM crash during onboard fast ram cycles.
    [U111_TOP_pin_table.CSV, U111_TOP_sbt.sdf, U111_TOP_sbt_vital.sdf]
2025-06-13 U400 : Fixed addressing issue with burst cycles.
    [U400_TOP_pin_table.CSV, U400_TOP_sbt.sdf, U400_TOP_sbt_vital.sdf]
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2025-06-14 U409 : Fixed latch timing for base addresses assigned by autoconfig.
    [U409_TOP_pin_table.CSV, U409_TOP_sbt.sdf, U409_TOP_sbt_vital.sdf]
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2025-06-22 U400 : Fixed SDRAM addressing issue.
    [U400_TOP_pin_table.CSV, U400_TOP_sbt.sdf, U400_TOP_sbt_vital.sdf]
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2025-09-15 U712: Fix chip ram timings
    Fixed video artifacts related to chip ram timing.
    [U712_TOP_pin_table.CSV, U712_TOP_sbt.sdf, U712_TOP_sbt_vital.sdf]
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2025-10-12 U409 - Fixed erroneous assertion of _TACK.
    [U409.pcf]
2025-10-16 U409 - new daily uploaded. See description.
    Changed _ROMEN assertion to be address driven.
    Fixed ROM wait states where 200ns (expected) was actually 250ns.
    Added new TICK timer based off 28MHz oscillator input, dropping part X1 and associated components.
    Rearranged folder structure to support RELEASE and DAILY Verilog and BINs.
    [U111_TOP_pin_table.CSV, U111_TOP_sbt.sdf, U111_TOP_sbt_vital.sdf]
2025-11-05 U409 Daily. See description.
    Adjust clocks to account for latency that was causing issue on some machines.
    New RTC state machine.
    Fixed issues with flash port size and buffer enable.
    [U409.pcf]
2025-11-07 U409 Daily 06-NOV-2025
    Fixed RTC address range.
    [U409.pcf]
2025-11-07 U409 Daily 07-NOV-2025
    Add chip selects for PCI bridge.
    Fix RTC address space.
    [U409.pcf]
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2025-11-14 U409 Daily 14-NOV-2025
    1) ATA fixed address at $BD0000 - $BDFFFF
    2) Added FLASH disable pin for future jumper
    3) Dropped AUTOCONFIG of PCI bridge in anticipation of fixed base at $80000000.
    [U409.pcf]

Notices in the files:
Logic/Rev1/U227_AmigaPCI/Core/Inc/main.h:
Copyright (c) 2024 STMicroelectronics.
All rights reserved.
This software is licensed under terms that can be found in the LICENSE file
